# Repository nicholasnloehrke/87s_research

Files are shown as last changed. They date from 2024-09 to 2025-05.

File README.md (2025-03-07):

# Code and hardware design files

## Block diagram

### Overall system

> TODO

### Controller 

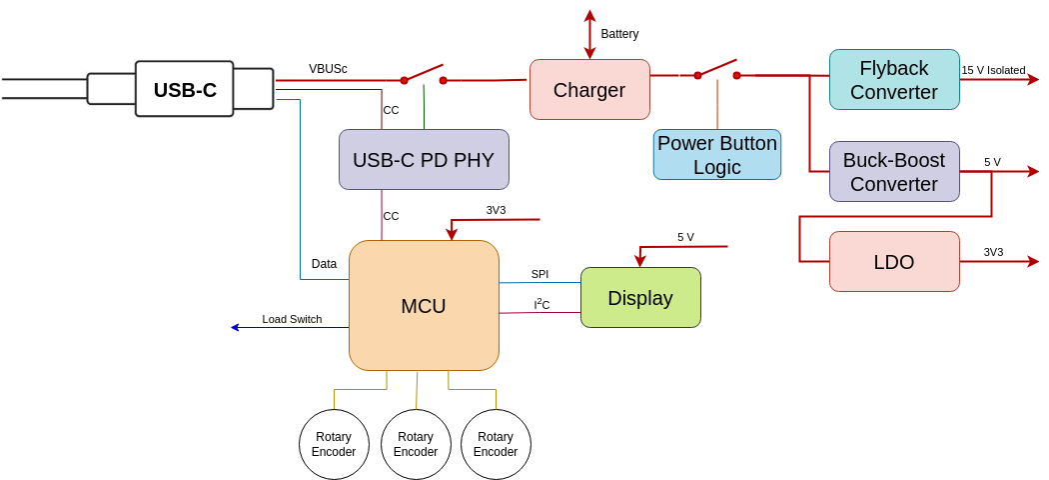
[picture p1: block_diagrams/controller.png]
controller_block_diagram


## Boards

### Bidirectional Load Switch

#### Known issues

- v0.1.0
    - Insufficient spacing on the AC connector 'AC\_in' net to 'earth' net
        - Workaround: Manually increase spacing
    - Lack of diode inline with 5 volt supply which would cause an issue if 5 volts and 3v3 (from ISP header) are supplied simultaneously 
        - Workaround: Don't supply both simultaneously
    - Lack of pulldown resistor on the !fault signal from the Attiny85 which could potentially have the gate driver inputs float, resulting in sporadic channel activation
        - Sporadic activation is likely only possible during power cycling as the gate drivers are internally pulled down.

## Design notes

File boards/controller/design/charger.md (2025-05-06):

# Charger IC's
    - BQ24707x
        - old
    - BQ24715
        - EVM avaliable
    - BQ24725A
        - EVM avaliable
    - BQ24735
        - EVM avaliable
    - BQ25792
        - EVM avaliable
        - Integrated FETs
        - Probably the easiest to design, assuming it meets the required specs

# Fuel Gauges
    - MAX17263

# BQ25792
    - Ship mode?
    - No USB D+/-?
    - V_AC?
    - Support 2-cell only?
        - If no, hardware jumpers or software configuration?
        - PROG pin sets *default* cell count, but can this be configured at runtime?
        - Seems like setting PROG to 1-cell and then configuring at runtime is possible.
          Need to consider safety concerns if MCU is setting charge voltages

## BQ25792 Power Sequencing
    - Minimum working voltage (rising)
        - VBAT
            - Min: 3.25, nominal: 3.40, max: 3.55 (ship mode)
            - Min: 2.50, nominal: 2.60, max: 2.71 (normal mode)
        - VBUS
            -

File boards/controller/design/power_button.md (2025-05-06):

# Power Button

The controller will implement a soft latching power circuit, as described
[here](https://circuitcellar.com/resources/quickbits/soft-latching-power-circuits/).
While it's possible to put the MCU and other peripherals into a sleep state,
removing power completely will result in the longest battery life in an off
state. Additionally, the LCD used was not designed with low power in mind, so
even in a sleep state there will be considerable power draw.

## Components
- Momentary switch
- Load switch (either an IC or discrete PMOS)
    - SIP32434ADN-T1E4

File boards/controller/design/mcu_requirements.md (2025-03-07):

# MCU Requirements

> This is a living document and will be updated continuously as requirements change

## Table

| Category | Requirement | Amount | Details |
|---|---|---|---|
| Memory | RAM | 700kB (min), ~1MB+ (preferred) | Needed for frame buffers (~614kB), LVGL (~48kB), and RTOS overhead |
| | Flash | 200kB (min), 1MB+ (preferred)  | LVGL (~100kB), FreeRTOS (~64kB). External QSPI flash likely needed with 200kB |
| Performance | General | N/A | Any MCU meeting RAM/Flash requirements should be sufficient |
| Peripherals | PWM | 1x (min), 8x (preferred) | For load switch channels |
| | SPI | 1x | Display |
| | I2C | 0x, 1x (preferred) | Display touch controller and STUSB4500 |
| | USB | 1x | For firmware updates and potential data logging |
| | QSPI | 0x, 1x (preferred) | For external flash |
| | GPIO | TBD | Needed for encoders, load switch, expansion |

## Discussion

### Memory

#### RAM

Fitting two frame buffers in memory would be ideal to allow for double buffering.  Tentatively, a 320 x 480 16BPP
display is to be used, requiring ~614kB for two buffers. LVGL claims 4kB + 150B/widget or '~48kB for a UI with a few
screens'. If we use a RTOS, extra RAM for thread stacks would be nice. With these considereations in mind, 700kB is
required and ~1MB or more of system RAM is preferred. 

#### Flash

I don't have a good idea of the flash requirements yet. LVGL wants ~100kB (depending on enabled features) and FreeRTOS
wants ~64kB (this is with TCP stack which we don't care about). More is certainly better, but we could probably get away
with some external QSPI flash if needed. I'm going to say ~200kB of onboard flash is a hard requirement, with 1MB total
being a nice to have. The tentative display has SD card support, but that uses the same SPI bus as the display driver,
so that's not ideal for reading/writing except at initialization.

### Performance

Performance is important, but just about any MCU that meets the RAM/flash requirements will be sufficient.

### USB-C Power Delivery

The STM32U5* chips have an integrated USB-C PD controller, but to reduce development time/complexity, I think using a
standalone STUSB4500 PD controller makes sense. It will take up some more board area and increase BOM count + cost, but
I think it still makes sense and reduces power sequencing complexity.

# Options
- STM32U575CGU3
    - Cheapest MCU on Digikey (thats in stock) that fits requirements
- STM32U575RITx
    - Similar to above, but with more IO

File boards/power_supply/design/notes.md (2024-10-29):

- BMS
    - https://liionbms.com/php/bms_chips_options.php
    - LTC6803
    - BQ769x0
    - ISL94202
    - ISL78600
    - L99BM114
    - LTC3300
    - LTC6804

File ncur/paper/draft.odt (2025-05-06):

Load Switch Circuit Module

The load switch circuit has seen significant improvements over the previous version. Version 2.0 retains the core design of back-to-back N-channel MOSFETs forming an AC switch but replaces the single-channel configuration and rotary switch for load selection [old schematic figure] with eight parallel switching channels [new schematic figure]. This upgrade allows for a much wider range of load resistances, as each channel can be independently controlled [resistance range figure]. The previous design faced reliability issues due to the rotary switch, a problem now eliminated with the solid-state implementation. Additionally, the new load switch integrates a microcontroller that reads an onboard Hall effect current sensor, providing over-current protection. The board maintains full compatibility with the previous version, supporting a single pulse-width modulation (PWM) input while also allowing up to eight PWM inputs for independent channel control. Each of the switching channels features galvanically isolated gate drivers with a working isolation voltage of 3.75 kVrms. The board logic side is powered by 5 VDC and the gate drivers are powered by an isolated 15-20 VDC supply. The onboard microcontroller provides either a simple GPIO interface, or UART.

Power Supply Module

The power supply module (PSM) has two primary functions: generating voltage rails and charging the battery. It utilizes two buck-boost converters to produce 5 VDC and 15 VDC power rails, with the 15 VDC rail isolated via a flyback converter. Texas Instruments TPS552872 buck-boost converters were selected for their wide input voltage range, enabling compatibility with various battery configurations. These converters also feature built-in protections, including output overvoltage protection, output short-circuit protection, and thermal shutdown. Designed to support 1–3 cell lithium-ion batteries, the PSM integrates a switch-mode battery charger from Monolithic Power Systems, offering configurable charge current and end-voltage settings. An onboard STM32U5 microcontroller negotiates power from any USB-C Power Delivery-compatible supply for charging. [schematic figure]

Battery Management System Module

Haven’t figured this part out yet, not sure if it should be included.

Microcontroller Unit

The microcontroller unit is built around an STM32U5, handling user input, display control, load switching, and USB communication. Menu navigation is achieved using three rotary encoders, allowing precise control of settings displayed on a 3.5-inch capacitive touch screen. The display operates over an SPI interface, while touch inputs are processed separately via an I2C bus to ensure smooth and responsive interaction.

To control the load switch, the microcontroller generates PWM signals with adjustable frequency and duty cycle. Additionally, USB functionality supports firmware updates, allowing end-users to upgrade the system without requiring specialized programming tools. This ensures long-term maintainability and easy deployment of software improvements or feature enhancements. [controller figure]

Comments/Questions

- How in-depth should I be going on the design process?
  - I could expand a ton on part selection, design tools, software, etc
- Keep power supply and microcontroller unit split up?
  - The initial design had separate boards, but now I’ve combined the functionally
- Talk about BMS?
  - This is going to be a store-bought item so idk if it needs it’s own section

Next Steps

- Finish up ‘module’ sections
  - Need schematics/other figures
- Add Version 1.0 sections
- Get into lab next week to do functional testing and collect data
- Order controller parts by next week or it won’t get done

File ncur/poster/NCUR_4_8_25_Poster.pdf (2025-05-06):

# University of Wisconsin-Platteville Electrical & Computer Engineering Department

# NATIONAL CONFERENCE ON UNDERGRADUATE RESEACHCUR 2025 Generator Stator Intermittent Ground Fault Test Instrument - Version 2.0

## Abstract:

The paper describes the design and fabrication of a novel intermittent ground fault (IGF) test instrument which aids system protection engineers to obtain solid or arcing fault data for evaluation of industrial generator stator ground protective relay settings.

# Nick Loehrke, Nader Safari-Shad, Owen Bauman, and Mason Kobliska

## Introduction:

Synchronous generators are critical to the stability and reliability of the power grid, making their protection against electrical faults essential for national security.
The most common generator fault is the stator single-phase ground fault which often begins as an intermittent ground fault (IGF). IGFs are characterized by high transient currents and overvoltages that can cause severe damage to insulation and generator components, potentially escalating into more severe faults and resulting in costly repairs and downtime.
Reports of stator IGF have sparked a renewed interest to develop reliable IGF detection schemes [1]-[3]. Specifically, [3] reports on development of a novel test instrument called 64S/87-TI version 1.0 by which stator IGF can be safely emulated on real-world generator stator neutral grounding circuits. Acquisition of such fault data can readily enable protective relay engineers to analyze the performance of new IGF detection schemes.
The goal of this paper is to propose upgrades to enhance the functionality of the 64S/87-TI version 1.0 reported in [3]. The primary upgrades include redesigning the electronic circuitry to incorporate a custom power supply module, battery management system, and improved load switch topology. The Arduino UNO microcontroller (MCU) used in [3] is also replaced with an STM32 MCU, offering increased processing power and flexibility. Additionally, the instrument enclosure is completely redesigned using a combination of extruded aluminum and CNC machined panels to ensure resilience to physical stresses.

## Conclusion:

## References:

[1] - IEEE Power System Relaying and Control Committee (PSRC) J12 Subcommittee Technical Report, “Improved Generator Ground Fault Schemes,” IEEE Power and Energy Society Technical Report -TR82, Sept. 1, 2020.
[2] - N. Safari-Shad, A. Sawadogo, R. Fechat and R. Franklin, ``Experimental Verification of an Intermittent Stator Ground Protection in Large MVA Generators," IEEE 26th International Conference on Electrical Machines, Torino, Italy, Sept. 1-4, 2024.
[3] - N. Safari-Shad and R. Franklin, ``Stator Intermittent Ground Fault Detection in High-Impedance Grounded Generators," IEEE 32nd International Symposium on Industrial Electronics, Aalto University, Helsinki-Espoo, Finland, June 19-21, 2023.

## Bidirectional Load Switch Module:

Fig. 3 shows the printed circuit board of the bidirectional load switch consisting of multiple fault resistance path to ground, MOSFET switches, and their gate drivers.

## Power Supply Module:

Fig. 2: Block diagram of the 64S/87TI

## Enclosure Design:

Fig. 1: Typical synchronous generator stator windings and connected protection equipment with the 64S/87S-TI

## Experimental Intermittent Ground Fault Realization:

64S/87S-TI is capable of staging solid or arcing single-phase ground fault on a real-world generator neutral or terminal phases. Fig. 1 shows the wiring diagram of a high impedance synchronous generator with the 64S/87-TI shown connected on the neutral point. Note that the generator stator ground protection is using a 64S subharmonic voltage injection along with a bandpass filter.

## 64S/87STI Version 2.0 Overall Architure:

Fig. 2 shows the overall block diagram of the 64S/87TI consisting of a battery, a battery management system (BMS), a custom designed power supply unit (PSU), a microcontroller (MCU), a bidirectional load switch circuit and a display.

Fig. 3: Block diagram of the 64S/87TI bidirectional switch circuit

Fig. 4: Block diagram of the 64S/87TI power supply module

## Microcontroller Unit:

Fig. 5: Block diagram of the of the 64S/87TI MCU

## Battery Management System:

Fig. 5: Block diagram of the 64S/87TI battery management system

Fig. 6: 64S/87S-TI Version 2.0 enclosure design

AC IN

CT IN | EARTH

CT OUT

CT

BNC

SCOPE

nINT

64S/87S -TI

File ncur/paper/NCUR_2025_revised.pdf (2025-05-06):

# Generator Stator Intermittent Ground Fault Test Instrument - Version 2.0

Nick Loehrke, Nader Safari-Shad, Owen Bauman, Electrical and Computer Engineering Department University of Wisconsin-Platteville Platteville, WI 53818, USA loehrken@uwplatt.edu
safarisn@uwplatt.edu
baumano@uwplatt.edu

Mason Kobliska
Huff Family Innovation Center
College of Engineering, Mathematics and Science University of Wisconsin-Platteville Platteville, WI 53818, USA kobliskam@uwplatt.edu

Abstract—The paper describes an improved design and fabrication of a novel intermittent ground fault (IGF) test instrument used in industrial generator stator ground protection. The improved instrument allows staging and acquisition of IGF data with higher precision and reliability. The instrument also enables more effective testing and validation of IGF detection algorithms contributing to the prevention of catastrophic generator stator ground faults and enhancing grid reliability.

Index Terms—Generator stator ground fault protection, and subharmonic voltage injection-based (64S) scheme.

I. INTRODUCTION

Synchronous generators are critical to the stability and reliability of the power grid, making their protection against electrical faults essential for national security.
The most common generator fault is the stator single-phase ground fault which often begins as an IGF. IGFs are characterized by high transient currents and overvoltages that can cause severe damage to insulation and generator components, potentially escalating into more severe faults and resulting in costly repairs and downtime [1] - [5].
Reports of stator IGF have sparked a renewed interest to develop reliable IGF detection schemes [6] - [8]. Specifically,
[8] reports on development of a novel test instrument called 64S/87S-TI Version 1.0 by which stator IGF can be safely emulated on real-world generator stator windings resulting in valuable fault data. Acquisition of such fault data enables protective relay engineers to analyze the performance of IGF detection schemes and assess their reliability.
The goal of this paper is to report on the upgrades enhancing the functionality of the 64S/87S-TI Version 1.0. The primary upgrades include redesigning the electronic circuitry to incorporate a custom power supply, battery management system, and improved load switch topology. The Arduino UNO microcontroller (MCU) in the 64S/87S-TI Version 1.0 is replaced with an STM32 MCU, offering increased processing power and flexibility. Additionally, the instrument enclosure is completely redesigned using a combination of extruded aluminum and CNC machined panels to ensure resilience to physical stresses.

II. IGF TEST INSTRUMENT - VERSION 1.0

The IGF test instrument named the 64S/87S-TI is an instrument designed and manufactured for stator insulation condition diagnosis in high-impedance grounded (HIG) generators [8]. Fig. 1 shows the typical schematic of the neutral grounding circuit equipped with the subharmonic voltage injection protection scheme 64S [9]. The 64S scheme is implemented using a subharmonic injection source, a bandpass filter,
a 64S protective relay [10], a current transformer (CT) | [11],
and | a neutral grounding transformer and resistor.

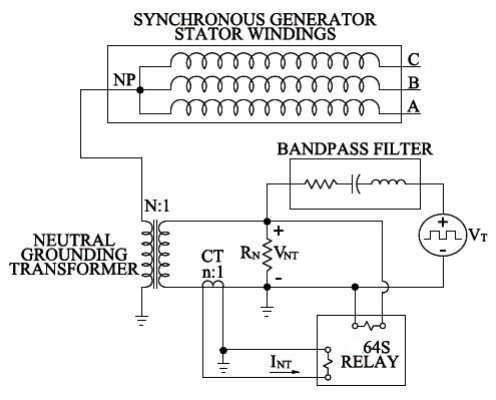
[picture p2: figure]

Fig. 1. Implementation of the 64S scheme in HIG generators

The instrument’s main function is to stage stator ground faults and measure the primary neutral grounding current on the grounding transformer low voltage side [8]. Two types of ground faults can be staged using the instrument: solid ground fault (SGF) and intermittent ground fault (IGF). Fig. 2 displays the front panel of the instrument.

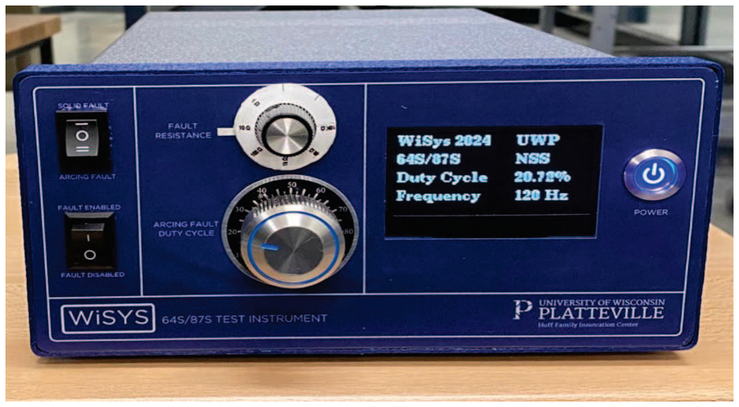
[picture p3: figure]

Fig. 2. IGF Test instrument - Version 1.0

A. SGF/IGF Test Setup

Fig. 3 shows the wiring diagram from the 64S/87S-TI to the generator neutral point. The setup is used for staging a solid or intermittent ground fault on the neutral side of the generator. When it is desired to stage a solid or intermittent ground fault on the terminal side of the generator, the AC IN connection is moved to one of the phases A, B, or C. The AC IN, EARTH, CT IN, and CT OUT connections are bundled in one plug-in port, respectively. The CT IN/OUT are, respectively, the input and output of a high-fidelity CT inside the 64S/87S-TI. The CT is capable of measuring high frequency neutral grounding current activity during intermittent ground fault [12].

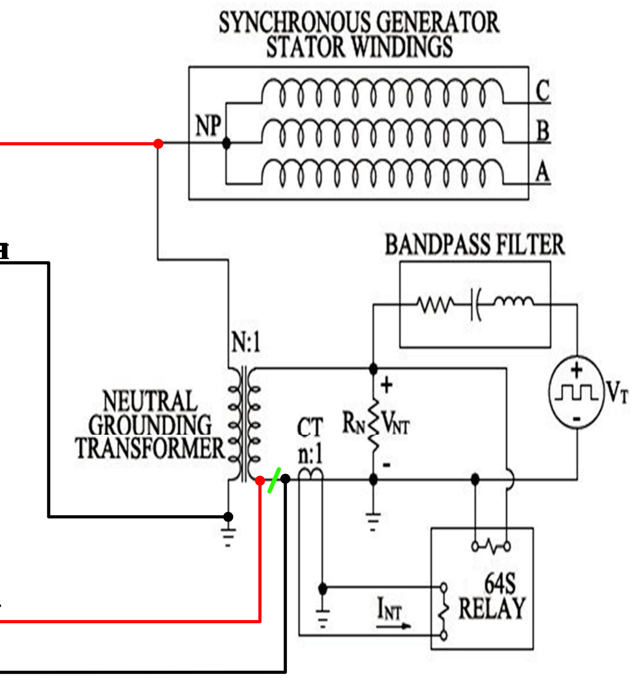
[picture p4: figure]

Fig. 3. 64S/87S-TI wiring connection diagram for fault staging

The principal component of the 64S/87S-TI is a single-channel AC bidirectional switch with a pair of MOSFETs, a gate driver IC and an Arduino UNO MCU. Moreover, a rotary switch is used for fault resistance selection. The complete assembly is referred to as the load switch circuit and is shown

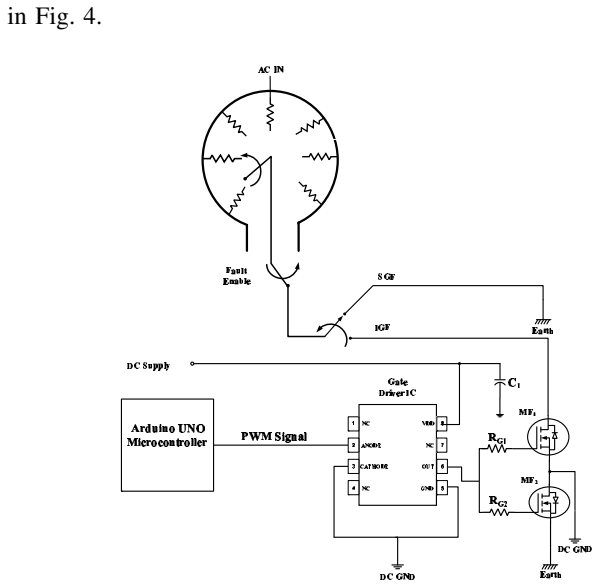
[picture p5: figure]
in Fig. 4.

Fig. 4. Load switch circuit in 64S/87S-TI - Version 1.0

III. IGF TEST INSTRUMENT - VERSION 2.0

The Version 1.0 of the instrument has been successfully implemented on a lab model of HIG generators to verify the reliability of a novel IGF detection scheme called the 87S [8]. However, in the process of this verification, a number of upgrades have been deemed necessary to improve the instrument’s functionality and performance. Specifically, the simple rechargable lithium-ion battery in Version 1.0 has been upgraded to an electronic circuitry for regulated power supply at 5VDC and 15VDC. In addition, a battery management system has been added to provide information on the state of battery charge. Moreover, the load switch circuit topology has been completely redesigned for optimal performance and its Arduino UNO MCU has been replaced with an STM32 MCU, offering increased processing power and flexibility. Finally, the instrument’s enclosure is completely redesigned using a combination of extruded aluminum and CNC machined panels to ensure resilience to physical stresses. The subsequent sections provide further details on all the upgrades.

A. Load Switch Circuit Module

The load switch circuit has seen significant improvements over the previous version. Version 2.0 retains the core design of the AC bidirectional switch shown in Fig. 4, but replaces the single-channel configuration and rotary switch for load selection with eight parallel switching channels as shown in Fig. 5.

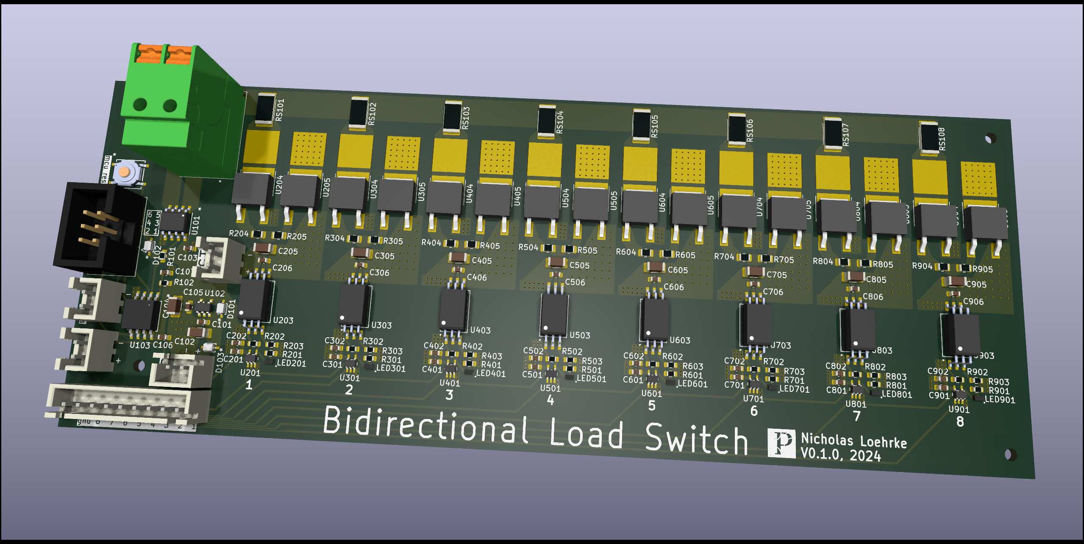
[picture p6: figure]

Fig. 5. Upgraded load switch circuit

This upgrade allows for a much wider range of fault resistances, as each channel can be independently controlled [resistance range figure]. The previous design faced reliability issues due to the rotary switch, a problem now eliminated with the solid-state implementation. Additionally, the new load switch integrates a microcontroller that reads an onboard Hall effect current sensor, providing overcurrent protection. The board maintains full compatibility with the previous version, supporting a single pulse-width modulation (PWM) input while also allowing up to eight PWM inputs for independent channel control. Each of the switching channels features galvanically isolated gate drivers with a working isolation voltage of 3.75 kVrms. The board logic side is powered by 5 VDC and the gate drivers are powered by an isolated 15-20 VDC supply. The onboard microcontroller provides either a simple GPIO interface, or UART.

B. Power Supply Module
The power supply module (PSM) has two primary functions: generating voltage rails and charging the battery. It utilizes two buck-boost converters to produce 5 VDC and 15 VDC power rails, with the 15 VDC rail isolated via a flyback converter. Texas Instruments TPS552872 buck-boost converters were selected for their wide input voltage range, enabling compatibility with various battery configurations. These converters also feature built-in protections, including output overvoltage protection, output short-circuit protection, and thermal shutdown. Designed to support 1−3 cell lithium-ion batteries, the PSM integrates a switch-mode battery charger from Mono-

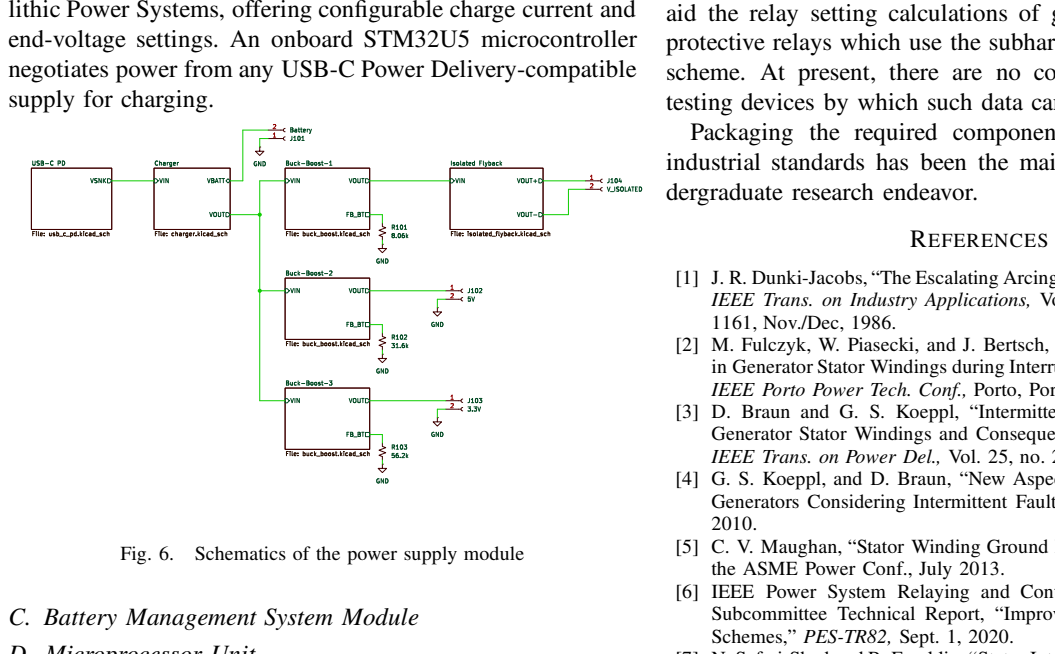
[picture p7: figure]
supply for charging.; C. Battery Management System Module; dergraduate research endeavor.; REFERENCES; 1161, Nov./Dec, 1986.; the ASME Power Conf., July 2013.; Schemes,” PES-TR82, Sept. 1, 2020.

lithic Power Systems, offering configurable charge current and end-voltage settings. An onboard STM32U5 microcontroller negotiates power from any USB-C Power Delivery-compatible

Fig. 6. Schematics of the power supply module

D. Microprocessor Unit
The microcontroller unit is built around an STM32U5, handling user input, display control, load switching, and USB communication. Menu navigation is achieved using three rotary encoders, allowing precise control of settings displayed on a 3.5-inch capacitive touch screen. The display operates over an SPI interface, while touch inputs are processed separately via an I2C bus to ensure smooth and responsive interaction. To control the load switch, the microcontroller generates PWM signals with adjustable frequency and duty cycle. Additionally, USB functionality supports firmware updates, allowing end-users to upgrade the system without requiring specialized programming tools. This ensures long-term maintainability and easy deployment of software improvements or feature enhancements. Fig. 7 shows the STM32U5 and the ancillary subsystems of the instrument.

IV. ENCLOSURE REDESIGN AND FABRICATION

V. FUNCTIONAL TESTING

VI. CONCLUSION
The paper describes the detailed steps to manufacture an enhanced version of an intermittent ground fault testing in-

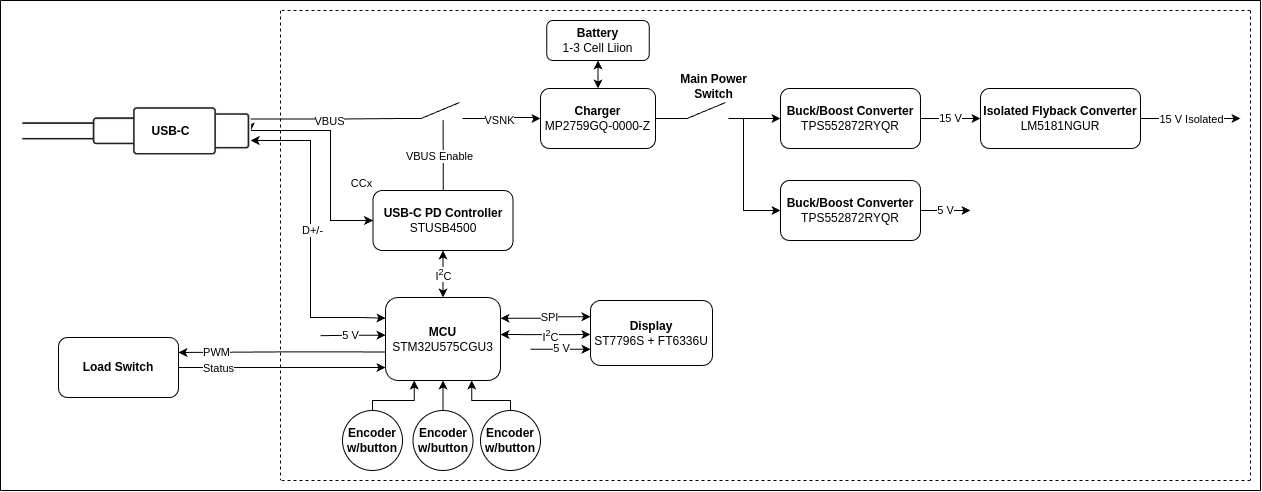
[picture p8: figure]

Fig. 7. Block diagram of the controller and the ancillary subsystems

strument by which generator stator intermittent and/or solid ground fault data can be simulated and stored. The stored data aid the relay setting calculations of generator stator ground protective relays which use the subharmonic voltage injection scheme. At present, there are no commercial ground fault testing devices by which such data can be collected. Packaging the required components in accordance with industrial standards has been the main objective of this un-

[1] J. R. Dunki-Jacobs, “The Escalating Arcing Ground-Fault Phenomenon,” IEEE Trans. on Industry Applications, Vol. IA-2225, no. 6, pp 1156-
[2] M. Fulczyk, W. Piasecki, and J. Bertsch, “Fast Transient Overvoltages in Generator Stator Windings during Interrupted Arcing Ground-Faults,” IEEE Porto Power Tech. Conf., Porto, Portugal, Sept. 2001.
[3] D. Braun and G. S. Koeppl, “Intermittent Line-to-Ground Faults in Generator Stator Windings and Consequences on Neutral Grounding,” IEEE Trans. on Power Del., Vol. 25, no. 2, pp 876-881, Apr. 2010.
[4] G. S. Koeppl, and D. Braun, “New Aspects for Neutral Grounding of Generators Considering Intermittent Faults,” CIDEL Argentinak, Sept.
[5] C. V. Maughan, “Stator Winding Ground Protection Failures,” Proc. of
[6] IEEE Power System Relaying and Control Committee (PSRC) J12 Subcommittee Technical Report, “Improved Generator Ground Fault
[7] N. Safari-Shad and R. Franklin, “Stator Intermittent Ground Fault Detection in High-Impedance Grounded Generators,” IEEE 32nd International Symposium on Industrial Electronics, Aalto University, Helsinki-Espoo, Finland, June 19-21, 2023.
[8] N. Safari-Shad and R. Franklin, “Experimental Verification of an Intermittent Ground Fault Detection in Large MVA Generators,” IEEE 26th International Conference on Electrical Machines, Torino, Italy, Sept. 1-4, 2024.
[9] S. Turner, “Applying 100% Stator Ground Fault Protection by Low Frequency Injection for Generators,” in Proc. IEEE Power Energy Soc. Gen. Meeting, pp. 1-6, Jul. 2009.
[10] “Beckwith Electric, M3425A Generator Protection Relay Instructional Book,” Beckwith Electric Inc. Publication.
[11] Flex Core Current Transformer, https://www.flex-core.com.
[12] MagneLab Current Transformer, https://gmw.com/product/ct/.

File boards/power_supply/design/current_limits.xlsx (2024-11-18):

Cell Charge Voltage | Charge Current |  | Voltage | Current | Power | PDO\Cell Count | 1 | 2 | 3
4.2 | 2 | PDO1 | 5 | 1 | 5 | PDO1 | no | no | no
 |  | PDO2 | 9 | 2 | 18 | PDO2 | yes | no | no
VIN to VBATT delta: | 2.4 | PDO3 | 15 | 2 | 30 | PDO3 | yes | yes | yes

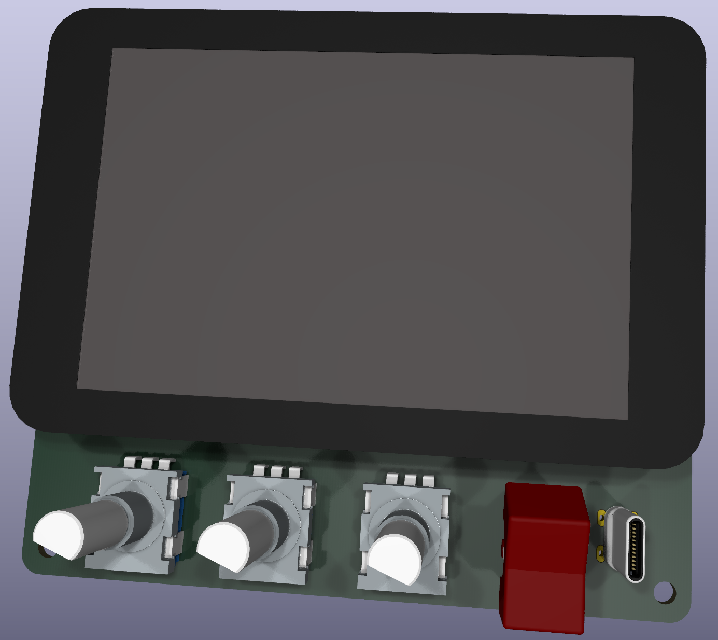
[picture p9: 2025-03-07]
ncur/media/controller-mockup-render.png

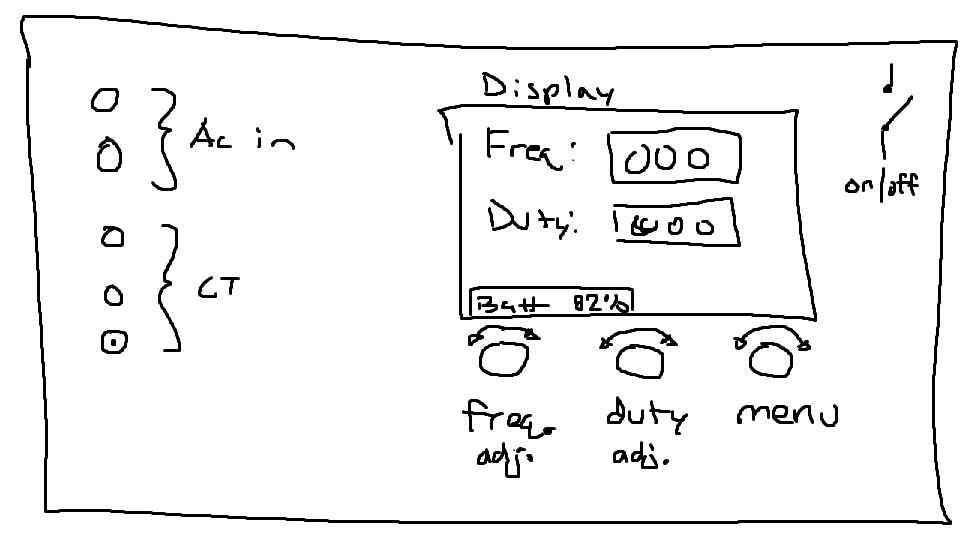
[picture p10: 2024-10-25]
docs/really_professional_front_panel_mockup.png

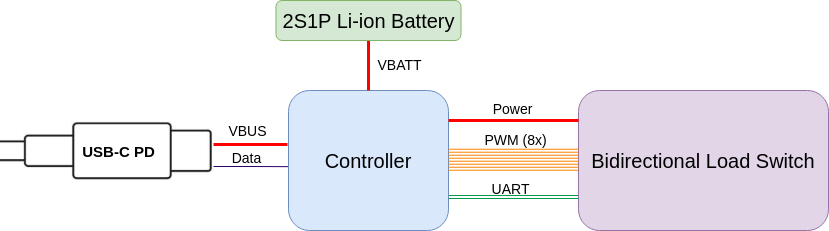
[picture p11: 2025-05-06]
block_diagrams/complete_system.png

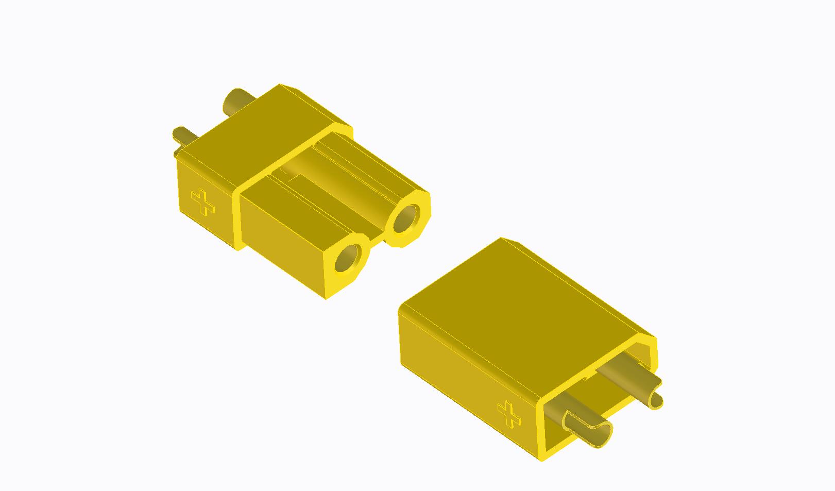
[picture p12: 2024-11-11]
boards/controller/pcb/symbols/XT30/XT30.jpg

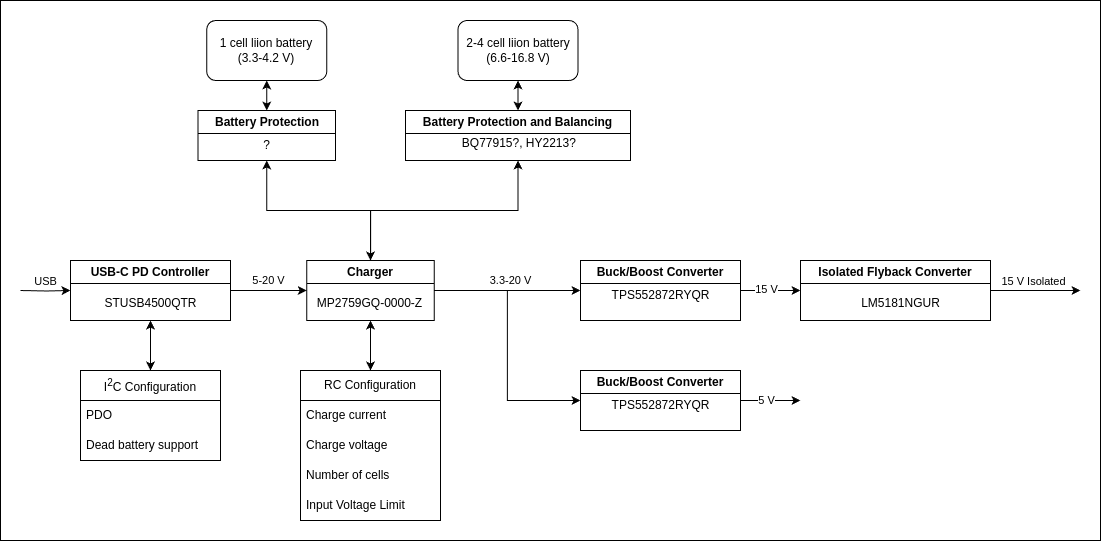
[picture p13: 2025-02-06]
block_diagrams/power_supply.png

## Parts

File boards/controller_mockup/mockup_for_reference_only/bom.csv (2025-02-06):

part | mfg_number | link
display | 3.5inch Capacitive Touch LCD 29318 | https://www.waveshare.com/3.5inch-Capacitive-Touch-LCD.htm
microcontroller | STM32U575CGU6Q | https://www.digikey.com/en/products/detail/stmicroelectronics/STM32U575CGU6Q/18086269
encoder | PEC12R-4120F-S0012 | https://www.digikey.com/en/products/detail/bourns-inc/PEC12R-4120F-S0012/4499657

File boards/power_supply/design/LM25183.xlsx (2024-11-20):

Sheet: LM(2)518x PSR flyback converter
LM5180/1 and LM25180/3/4 PSR Flyback Design Tool
About | xx (http://www.ti.com/widevin) |  |  | = Input Box |  |  |  |  |  | Terms Of Use
Step 1: Operating Specifications |  |  |  |  |  | Step 2: Flyback Transformer
 |  | Input Voltage – Min, VIN(min) | 9 | V |  |  | Minimum Magnetizing Inductance | 50.8 | µH
 |  | Input Voltage – Nom, VIN(nom) | 20 | V |  |  | Magnetizing Inductance, LMAG | 150 | µH
 |  | Input Voltage – Max, VIN(max) | 21 | V |  |  | Primary Winding DCR | 800 | mΩ
 |  | Single Output or Dual Outputs |  |  |  |  | Secondary Winding DCR | 796 | mΩ
 |  | Output Voltage, VOUT | 20 | V |  |  |  | 50
 |  | Rated Output Current, IOUT | 0.1 | A |  |  | Pri-Sec Leakage Inductance | 3000 | nH
 |  |  | -16 |  |  |  | Transformer Turns Ratio, Pri : Sec
 |  |  | -0.1 |  |  |  | SW Voltage at VIN(max) - Spike Not Included | 41 | V
 |  |  |  |  |  |  | Max Output Current at VIN(min) | 0.11 | A
Step 3: Input & Output Capacitors |  |  |  |  |  |  | Duty Cycle at VIN(min) | 69.4 | %
 |  | Minimum Input Capacitance | 2.2 | µF |  |  | Primary Winding DCR Loss at Vin(nom) | 36.481901 | mW
 |  | Input Capacitance, CIN | 10 | µF |  |  |  | 22.37904887 | mW
 |  | Input Capacitor ESR | 3 | mΩ |  |  | Peak Primary Current at Vin(nom) | 0.44 | A
 |  | Resulting Input Voltage Ripple | 36.50007233 | mVpk-pk |  |  | Peak Secondary Current at Vin(nom) | 0.44 | A
 |  | Minimum Output Capacitance | 7.557870065 | µF |  |  |  | 4.7 | µF
 |  | Output Capacitance, COUT | 20 | µF |  |  | Output Capacitance, COUT2 | 22 | µF
 |  | Output Capacitor ESR | 3 | mΩ |  |  | Output Capacitor ESR | 2 | mΩ
 |  | Resulting Output Voltage Ripple | 17.53692 | mVpk-pk |  |  |  | 12.83484433 | mVpk-pk
Step 4: Feedback, Soft-start, TC, UVLO
 |  | Recommended Feedback Resistor | 203.2 | kΩ
 |  | Selected Feedback Resistor, RFB | 203.2 | kΩ
 |  | Soft-Start Configuration
 |  | *Leave SS Pin Open or Supply by Ext. Bias | 20 | ms
 |  | Soft-Start Capacitance, CSS | 100 | nF
 |  | VOUT Thermal Compensation
 |  | *Leave TC Pin Open | -1.5 | mV/°C
 |  | Thermal Compensation Resistor, RTC | 402 | kΩ
 |  | Input UVLO Configuration
 |  | *Connect EN pin to VIN or Logic HIGH | 8 | V
 |  |  | 7.5 | V
 |  | Upper UVLO Resistor, RUV1 | 46.4 | kΩ
 |  | Lower UVLO Resistor, RUV2 | 10.7 | kΩ
Step 5: Power Losses & Thermals
 |  | Flyback Diode Voltage Drop, VD(no-load) | 0.32 | V
 |  | Flyback Diode Voltage Drop, VD(full-load) | 0.4 | V
 |  | Estimated IC Thermal Impedance, JJA | 41 | °C/W
 |  | Ambient Temperature, TA | 55 | °C
 |  | Power Dissipation at Full Load, PD | 46.71808189 | mW
 |  | Junction Temperature at Full Load, TJ | 56.91544136 | °C
Step 6: Optional RC Snubber across Rectifier Diode |  |  |  |  | (Always reserve the snubber positions on PCB, and validate by experiments.)
 |  | Recommended Csnb | 22 | pF
 |  | Snubber Capacitor Voltage Rating > | 61.5 | V
 |  | Recommended Rsnb | 100 | Ω
 |  | Snubber Resistor Power Dissipation Rating > | 0.116 | W
Step 7: Optional Output Zener Clamp or Dummy Load |  |  |  |  | (Always reserve the Zener clamp and dummy load position on PCB)
 |  | Min Load Current, IOUTmin | 0.005 | A |  |  |  | -0.005
 |  | Max Output Voltage Limit, VOUTmax | 22.00 | V |  |  |  | -17
 |  | Zener Clamp Dz or Dymmy Load Rdmy | None
 |  | Selection | None
 |  | Selected Device Min Power Rating> | N/A | W

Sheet: BOM & Schematic
SINGLE Output PSR Flyback Converter, VIN = 20 V, VOUT = 20 V, IOUT = 0.1 A
LM5181 High Efficiency PSR Flyback Converter BOM
Count | Ref Des | Value | Description | Size | Part Number | MFR | Footprint (mm) | Area (mm2)
1 | CIN | 10µF | Capacitor, Ceramic, 10µF, 50V, X7R, 10% |  | Std | Std | 3.2 x 2.5 | 8.0 |  |  |  | 5
1 | COUT | 20µF | Capacitor, Ceramic, 20µF, 25V, X7R, 10% |  | Std | Std | 3.2 x 2.5 | 8.0 |  |  |  | 5
- | COUT2 | - | - |  | - | - | - | - |  |  |  | 5
- | - | - | - | 0603 | - | - | - | - |  |  |  | 1
1 | DFLY | Diode | Rectifying Diode, Schottky | #NAME? | Std | Std | 5.0 x 2.5 | 12.5 |  |  |  | 4
- | DFLY2 | - | - | 0603 | - | - | - | - |  |  |  | 3
1 | DF | Diode | Clamp Circuit Diode, Fast Recovery |  | Std | Std | 3.6 x 1.8 | 6.5 |  |  |  | 3
1 | DCLAMP | 26V | Clamp Circuit Diode, Zener, 26V | 0603 | Std | Std | 3.6 x 1.8 | 6.5 |  |  |  | 3
1 | DOUT | 22V | Output Clamp Diode, Zener, 22.5V |  | Std | Std | 1.6 x 0.8 | 1.3 |  |  |  | 1
1 | RSET | 12.1k | Resistor, Chip,12.1kΩ, 1/16W, 1% | 0603 | Std | Std | 1.0 x 0.5 | 0.5 |  |  |  | 1
1 | RFB | 203.2k | Resistor, Chip,203.2kΩ, 1/16W, 1% | 0603 | Std | Std | 1.0 x 0.5 | 0.5 |  |  |  | 1
- | RUV1 | - | - | 0603 | - | - | - | - |  |  |  | 1
- | RUV2 | - | - | 0603 | - | - | - | - |  |  |  | 1
- | RTC | - | - | 0603 | - | - | - | - |  |  |  | 1
1 | T1 | 150µH | Transformer, 150µH, 1 : 1, 800mΩ Pri DCR, 1A Isat | - | Various | Various | 10 x 10 | 100 |  |  |  | 5
1 | U1 | LM5181 | IC, LM5181, PSR Flyback Converter, 4.5V–65V Input | WSON-8 | LM5181NGUR | TI | 4.0 x 4.0 | 16.0
 |  |  |  |  | Total Solution Size (buffered by 25%) |  |  | 199.8 | mm2 = | 0.3096 | in2
NOTES:
1. Choose a transformer with saturation current rating higher than the max peak current limit setting (1.73A) for all operating temperatures
2. Appropriately derate the effective input and output capacitances for applied voltage and temperature, particularly with ceramics
3. Use a primary-side RC snubber from SW to VIN to dampen leakage inductance spike
4. Use a flyback diode RC snubber to dampen ringing if needed
5. Use an output zener to clamp the output at no load

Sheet: EVM Examples Layouts
LM5180/1 and LM25180/3/4 PSR Flyback Converter Design Tool
 | LM5180EVM-S05 PCB Design, 2" x 1.4" (50mm x 35mm) | LM5180EVM-DUAL PCB design, 2.1" x 1.5" (55mm x 38mm) | LM25184EVM-S12 PCB design, 2.2" x 1.4" (56mm x 36mm)

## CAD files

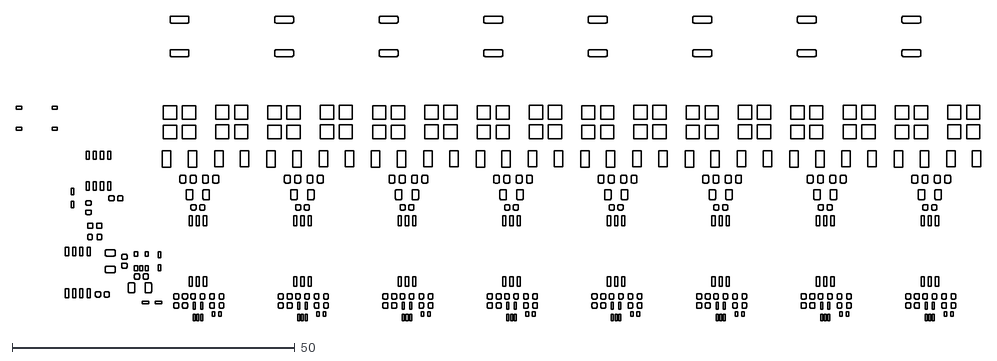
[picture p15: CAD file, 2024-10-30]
boards/bidirectional_load_switch/assembly/paste.dxf
170.7 x 53.9

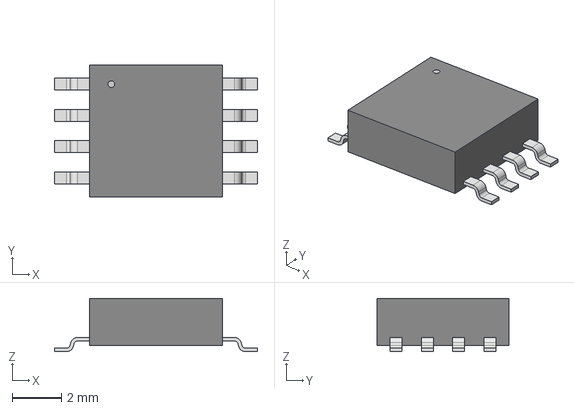
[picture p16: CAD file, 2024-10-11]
boards/bidirectional_load_switch/pcb/symbols/ATTINY85_20SU/8S2_ATM.step
8.26 x 5.36 x 2.16 mm

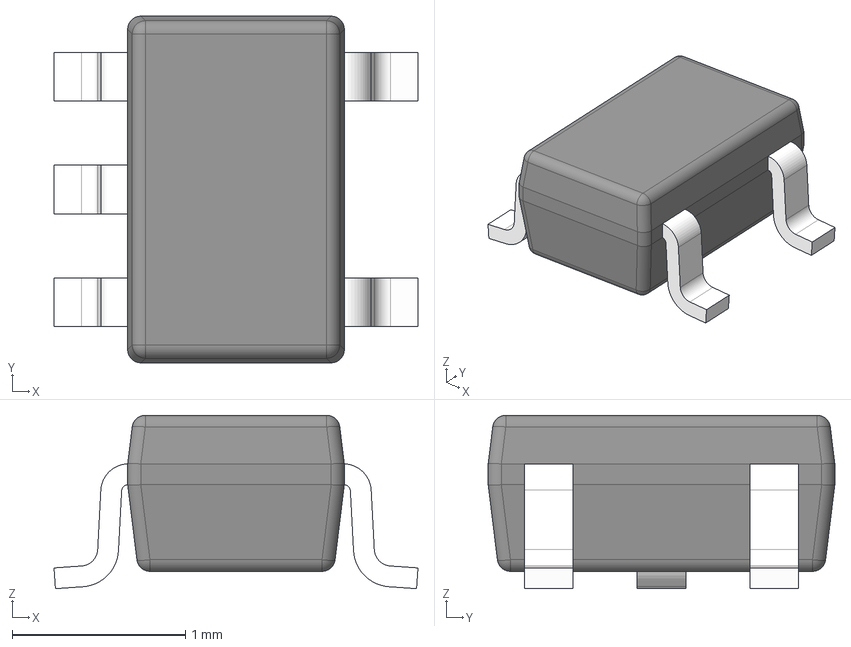
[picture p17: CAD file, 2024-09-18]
boards/bidirectional_load_switch/pcb/symbols/SN74LVC1G08DCKR/DCK0005A.stp
2.10 x 2.00 x 1.00 mm
BODY-SOT
LEAD-SOT x 5
PIN1-ID

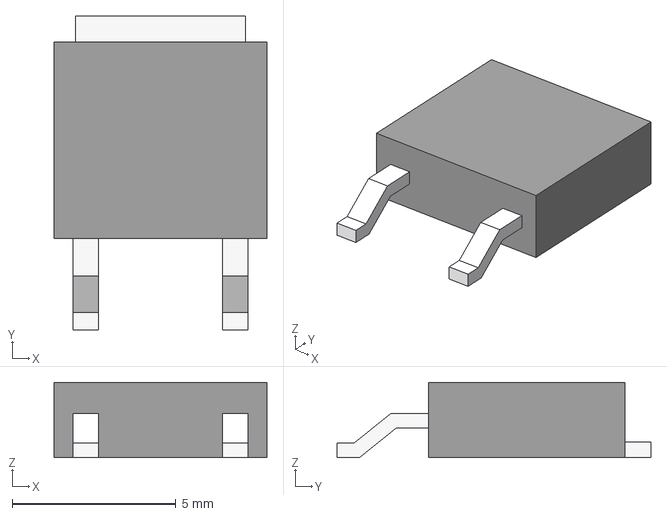
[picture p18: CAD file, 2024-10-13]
boards/bidirectional_load_switch/pcb/symbols/STD16N60M6/new_mosfet.step
6.50 x 9.60 x 2.30 mm

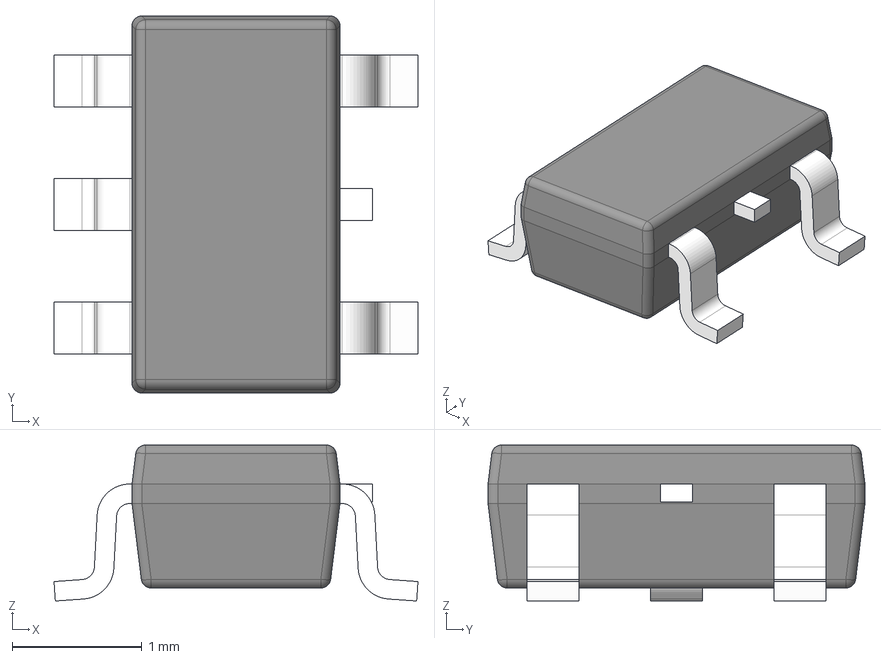
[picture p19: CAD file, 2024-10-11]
boards/bidirectional_load_switch/pcb/symbols/TLV75733PDBVR/DBV0005A.stp
2.80 x 2.90 x 1.20 mm
BODY-SOT
LEAD-SOT x 5
LEAD-DUMMY

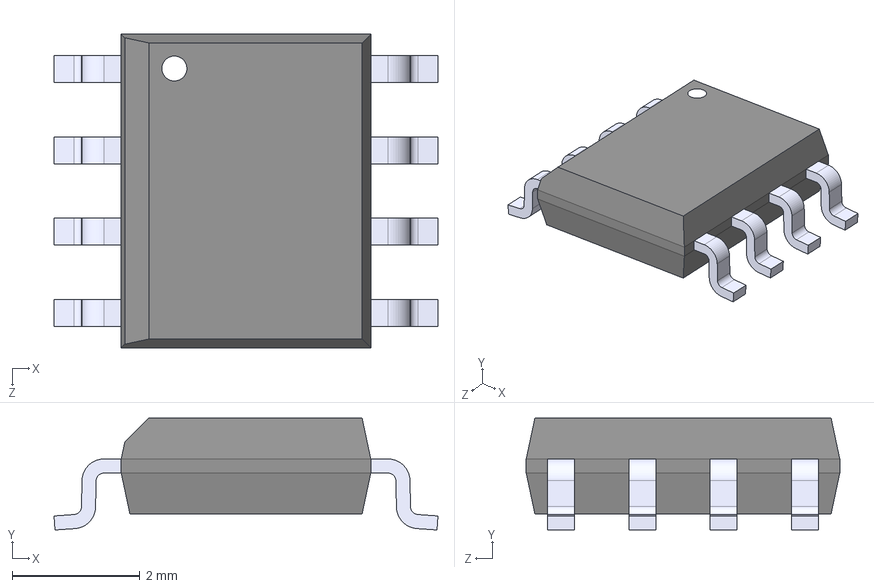
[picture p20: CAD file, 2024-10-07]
boards/bidirectional_load_switch/pcb/symbols/TMCS1101A3BQDR/TMCS1101A3BQDR.step
6.00 x 1.75 x 4.90 mm

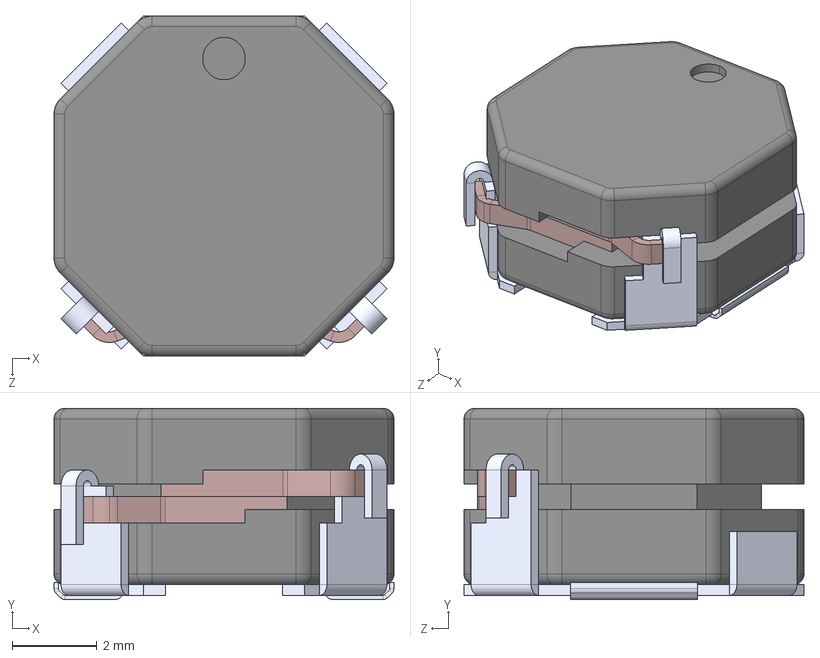
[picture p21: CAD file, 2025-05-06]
boards/controller/pcb/symbols/1217AS-H-3R3N-P3/1217AS-H-3R3N-P3.step
8.00 x 4.50 x 8.00 mm

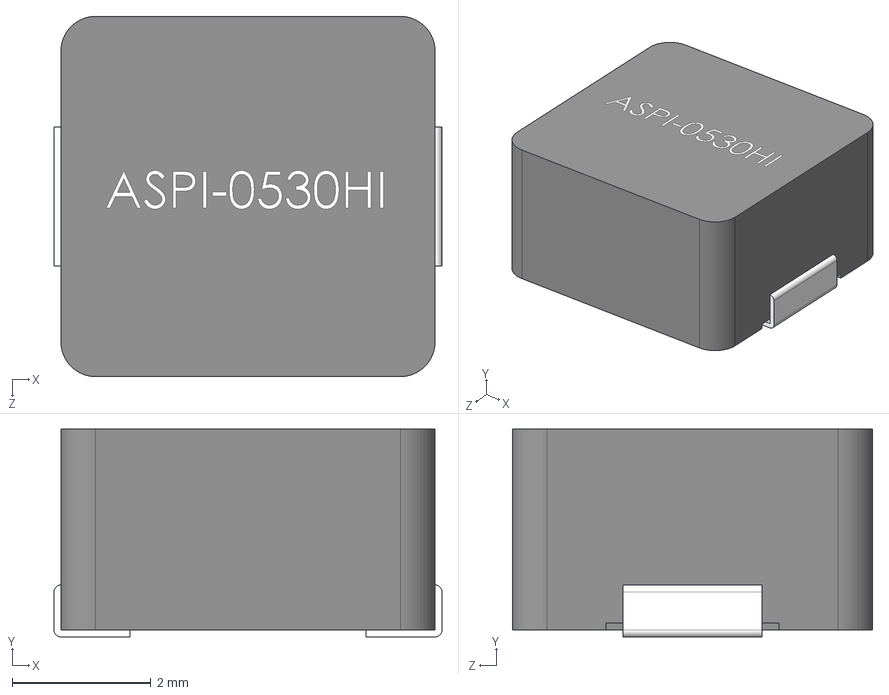
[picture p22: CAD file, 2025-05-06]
boards/controller/pcb/symbols/ASPI-0530HI-1R0M-T2/ASPI-0530HI-1R0M-T2.step
5.60 x 3.00 x 5.20 mm

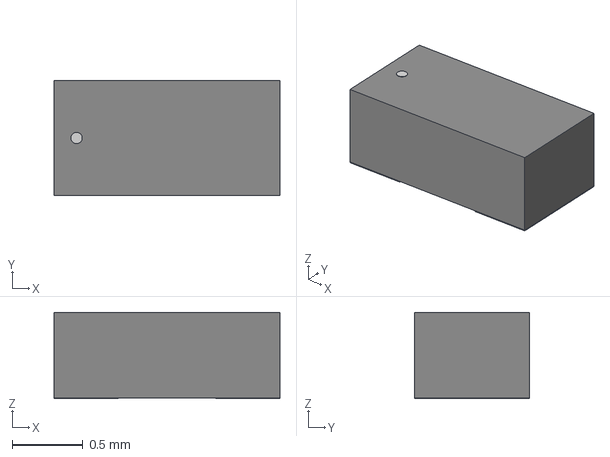
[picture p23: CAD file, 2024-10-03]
boards/controller/pcb/symbols/B1911PG--20D000514U1930/B1911PG--20D000514U1930.step
1.60 x 0.812 x 0.612 mm

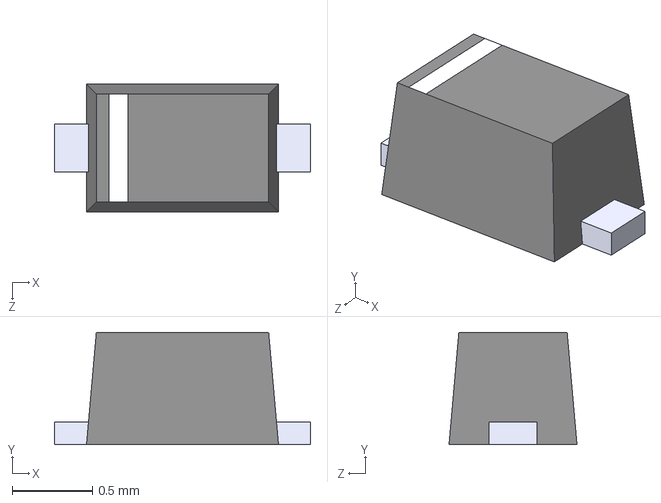
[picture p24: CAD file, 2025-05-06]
boards/controller/pcb/symbols/BZT52C18K_RKG/BZT52C18K_RKG.step
1.60 x 0.7 x 0.8 mm

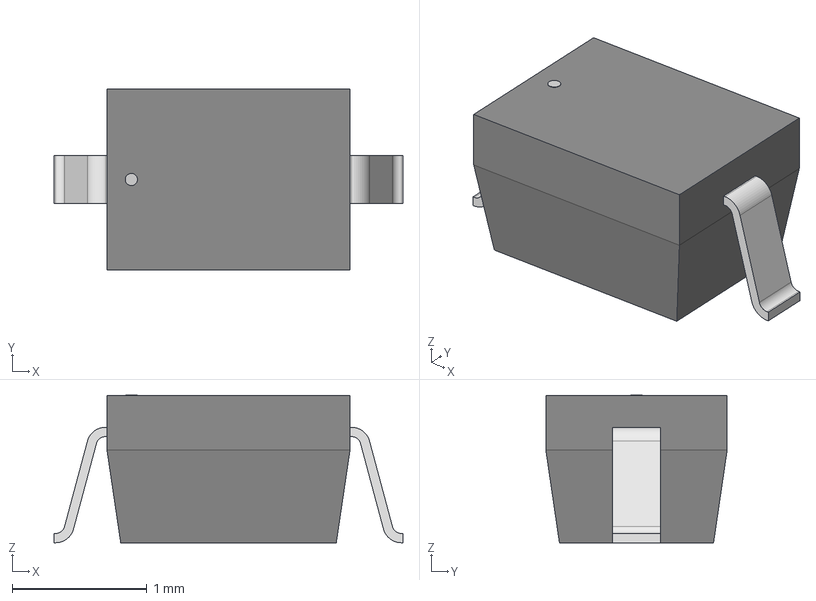
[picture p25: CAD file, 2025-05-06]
boards/controller/pcb/symbols/CMDD4448/CMDD4448.step
2.59 x 1.35 x 1.09 mm

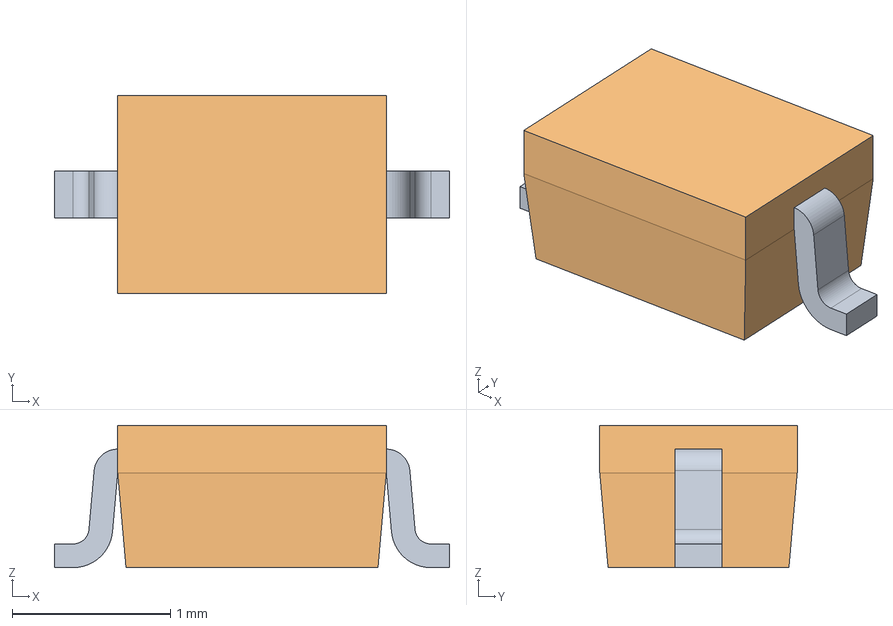
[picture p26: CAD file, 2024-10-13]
boards/controller/pcb/symbols/CUS10S30_H3F/CUS10S30_H3F.stp
2.50 x 1.25 x 0.9 mm

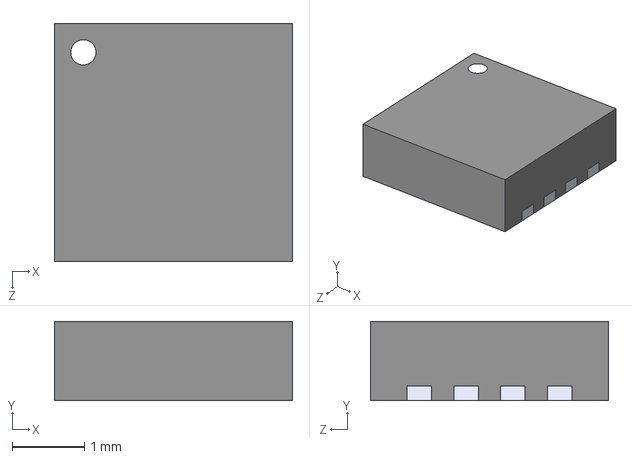
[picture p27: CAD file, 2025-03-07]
boards/controller/pcb/symbols/ISZ065N03L5SATMA1/ISZ065N03L5SATMA1.step
3.30 x 1.10 x 3.30 mm

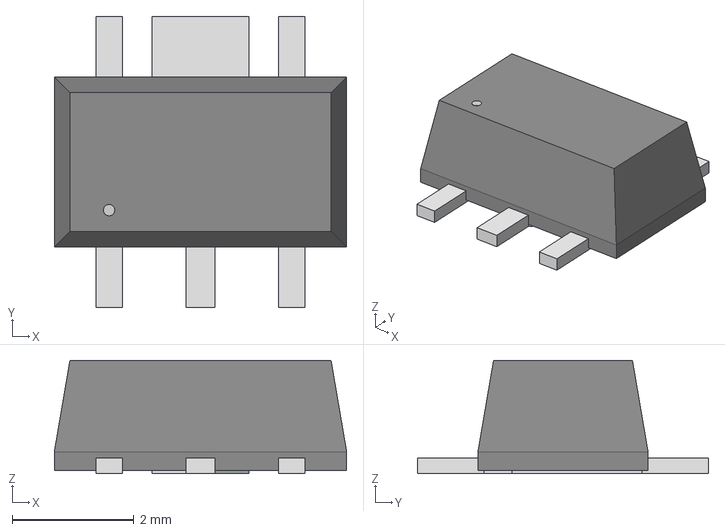
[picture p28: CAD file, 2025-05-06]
boards/controller/pcb/symbols/NJM2884U1-33-TE1/NJM2884U1-33-TE1.step
4.80 x 4.78 x 1.86 mm

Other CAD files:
boards/controller/pcb/symbols/PJSD03TS-AU_R1_000A1/PJSD03TS-AU_R1_000A1.step
boards/controller/pcb/symbols/RH100-16.000-18-2030-EXT-TR/RH100-16.000-18-2030-EXT-TR.step
boards/controller/pcb/symbols/SISA35DN-T1-GE3/SISA35DN-T1-GE3.STEP
boards/bidirectional_load_switch/pcb/symbols/1017503/1017503.step
boards/bidirectional_load_switch/pcb/symbols/UCC23313DWYR/UCC23313DWYR.STEP
boards/controller-old/pcb/symbols/12401826E412A/12401826E412A.step
boards/controller-old/pcb/symbols/12402012E212A/12402012E212A.step
boards/controller-old/pcb/symbols/750315829/750315829.STEP
boards/controller-old/pcb/symbols/PTS526_SK15_SMTR2_LFS/PTS526_SK15_SMTR2_LFS.STEP
boards/controller-old/pcb/symbols/SK34SMA-3G/SK34SMA-3G.step
boards/controller-old/pcb/symbols/USB4105-GF-A/USB4105-GF-A.step
boards/controller-old/pcb/symbols/USB4120_03_C/USB4120-03-C.step
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

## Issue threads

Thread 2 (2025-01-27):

Feature: Design Controller

nicholasnloehrke, 2025-01-27:
### **Motivation**
This project requires a controller capable of generating a PWM signal to drive a bidirectional load switch. The controller shall allow users to adjust the PWM signal's frequency and duty cycle, as well as the load switch resistance.

A previous version utilized an [Arduino UNO R4 WiFi](https://store.arduino.cc/products/uno-r4-wifi), an OLED display, and rotary encoders. This proposal seeks to improve on that design while reducing unnecessary complexity and cost.

---

### **Proposal**
The proposed solution will use the following components:

- **MCU**: [RP2350](https://lectronz.com/products/rp2350-stamp)
- **Display**: [ILI9486](https://a.co/d/eUZY2BM)
- **Input**: Rotary encoders

These components balance cost, ease of use, and performance. If WiFi is needed, an [ESP32 module](https://www.adafruit.com/product/5670?gQT=2) could be used in place of the RP2350.

The RP2350 is particularly appealing due to its PIO capabilities to drive the ILI9486's 16-bit parallel interface. Alternatively, an STM32 with an FMC peripheral could be considered.

---

### **Mockup**
Here’s a simple conceptual diagram of the proposed layout:

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

---

### **Advantages**
- **Hardware Simplification**: MCU and display modules reduce layout complexity.
- **Software Readiness**: I've ported an industry standard graphics library ([LVGL](https://lvgl.io/)) to the RP2350 and ILI9486.

---

### **Next Steps**
1. **Component Finalization**: Confirm the MCU, display, and rotary encoder specifications.
2. **Schematic Design**: Create the circuit schematic in KiCad.
3. **PCB Layout**: Begin designing the PCB based on finalized hardware choices.

nicholasnloehrke, 2025-01-28:
Updated motivation section to include abitily to change load switch resistance

nicholasnloehrke, 2025-02-06:
Combining the PSU into the controller might be a good idea. This would reduce the BOM and not require long wires to connect the STUSB4500 to the MCU.

nicholasnloehrke, 2025-02-06:
> Planning to use STM32xxx since we can't source the RP2350 chip and the castellated modules are pricy when including shipping.

Need to check if STM32U5xx has enough ram for 1 frame buffer (ideally 2 buffers).

nicholasnloehrke, 2025-02-06:
> Planning to use STM32xxx since we can't source the RP2350 chip and the castellated modules are pricy when including shipping.

Need to determine if SMPS sku (STM32U575xxxxQ) is desirable.

nicholasnloehrke, 2025-02-11:
STM32U575x might not have enough IO, might consider [STM32H7B0VBT6](https://www.digikey.com/en/products/detail/stmicroelectronics/STM32H7B0VBT6/11591224) even though this will probably required external flash.

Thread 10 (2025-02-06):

Update block diagrams to reflect BOM changes

nicholasnloehrke, 2025-02-06:
Current block diagrams specify the RP2350 and ILI9488 instead of STM32xxx and the Waveshare display.

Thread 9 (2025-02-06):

Fix documentation CI pushing to main

nicholasnloehrke, 2025-02-06:
The main branch is protected and can only be merged through a PR. Currently, the documentation CI tries to push directly to main and fails.

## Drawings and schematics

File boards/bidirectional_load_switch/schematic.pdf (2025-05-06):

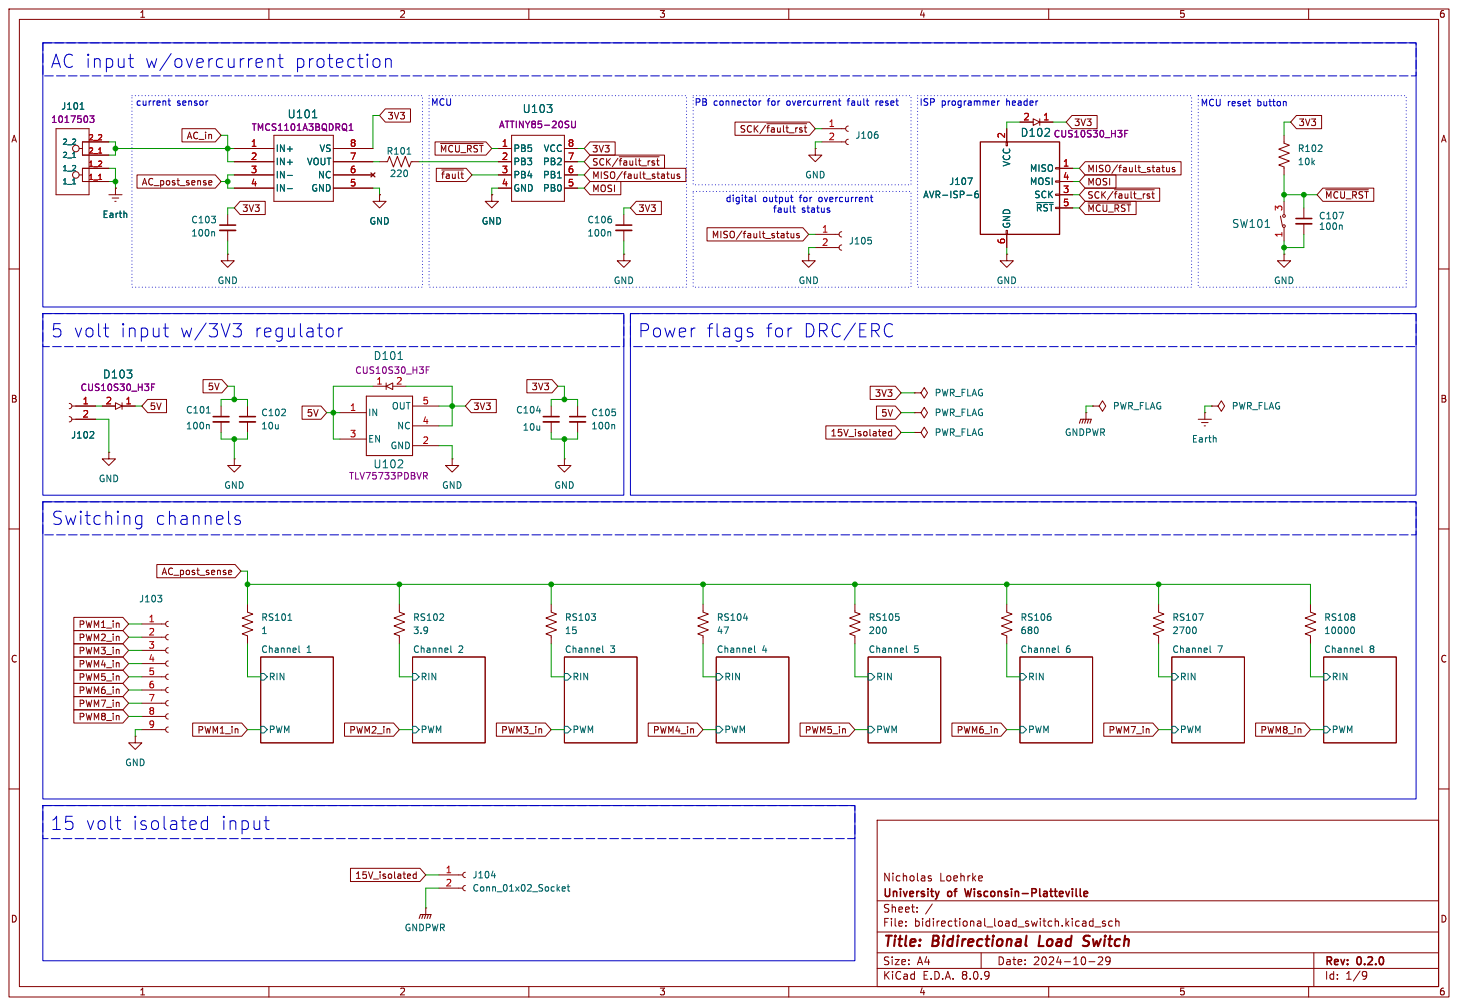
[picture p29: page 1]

MCU reset button Switching channels

2 SCK 3 MOSI 4 ~{RST}5 GND

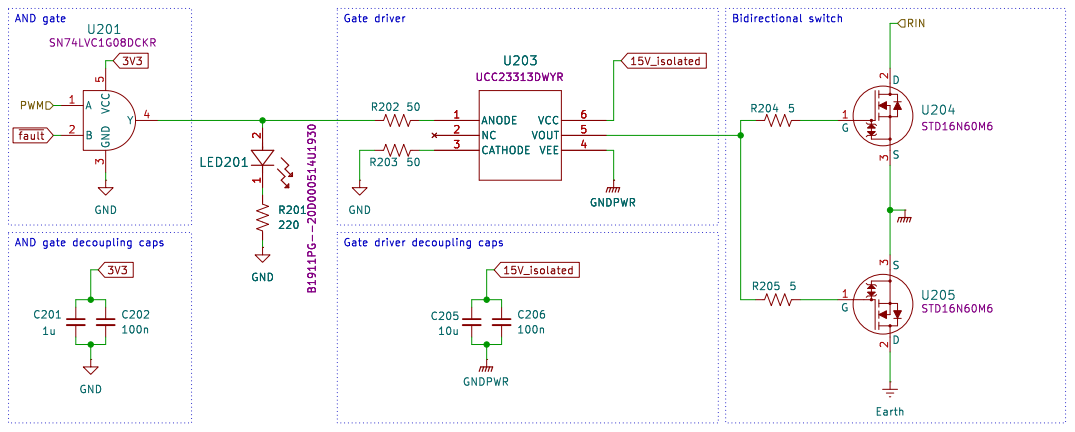
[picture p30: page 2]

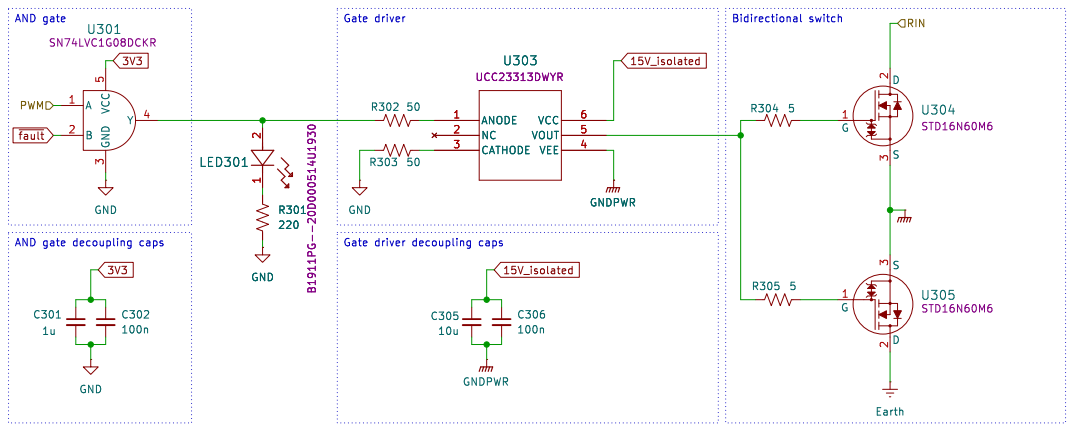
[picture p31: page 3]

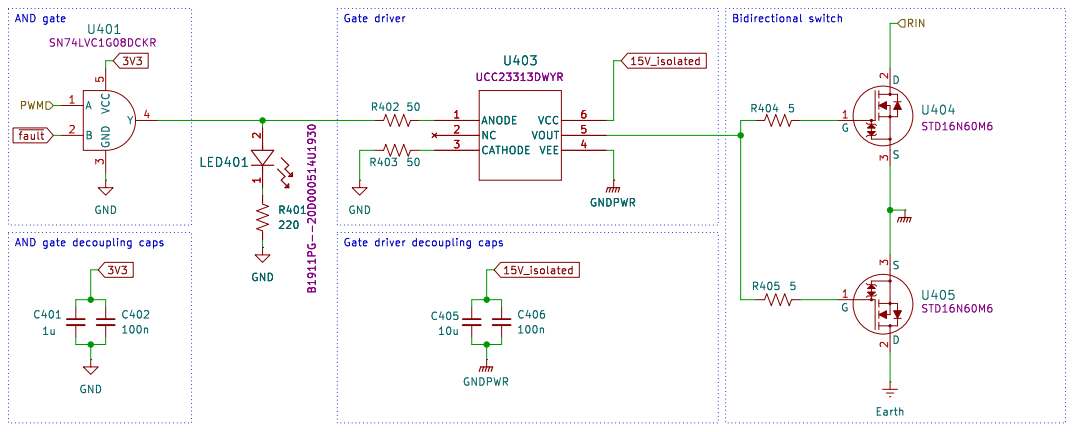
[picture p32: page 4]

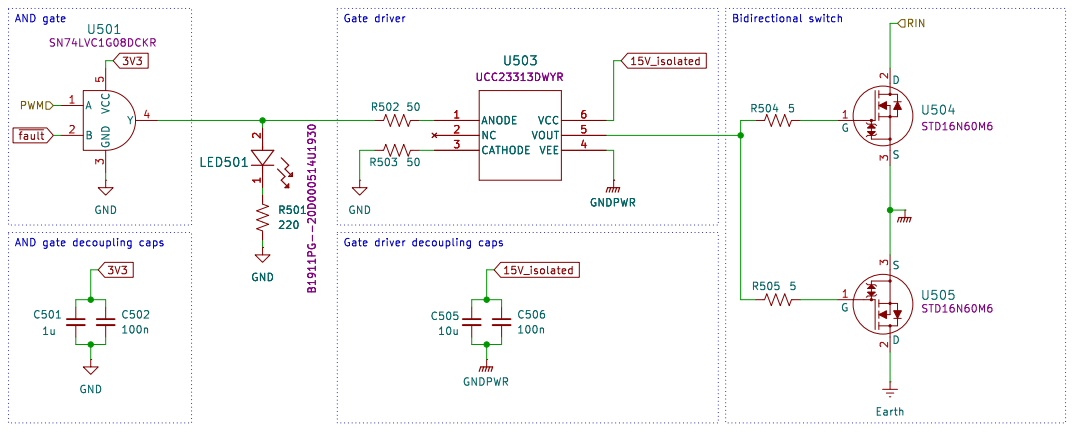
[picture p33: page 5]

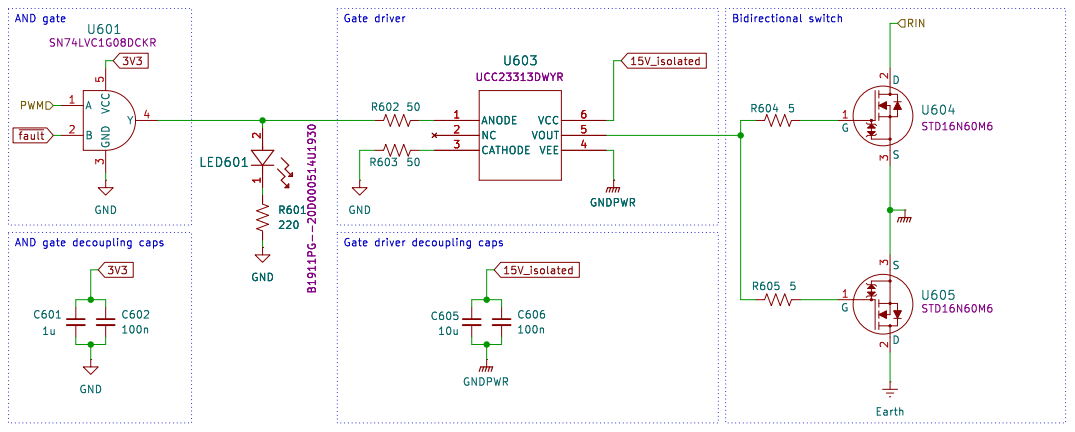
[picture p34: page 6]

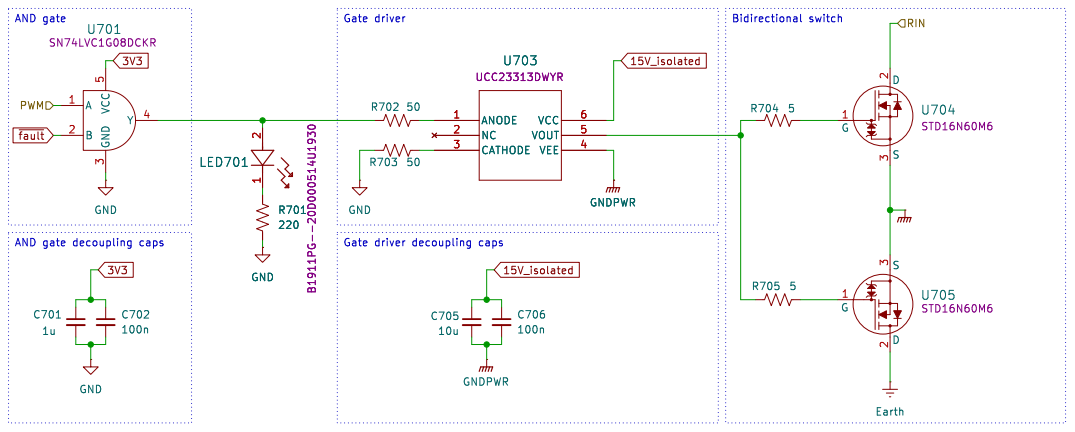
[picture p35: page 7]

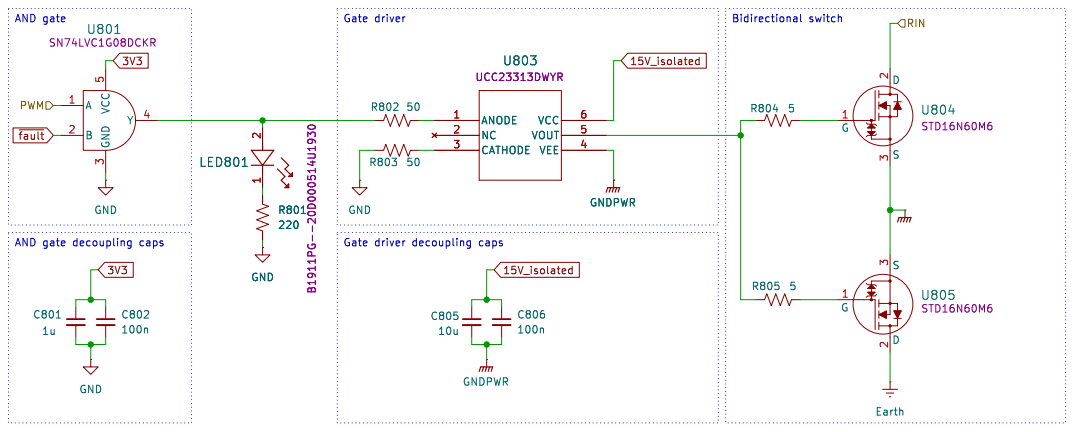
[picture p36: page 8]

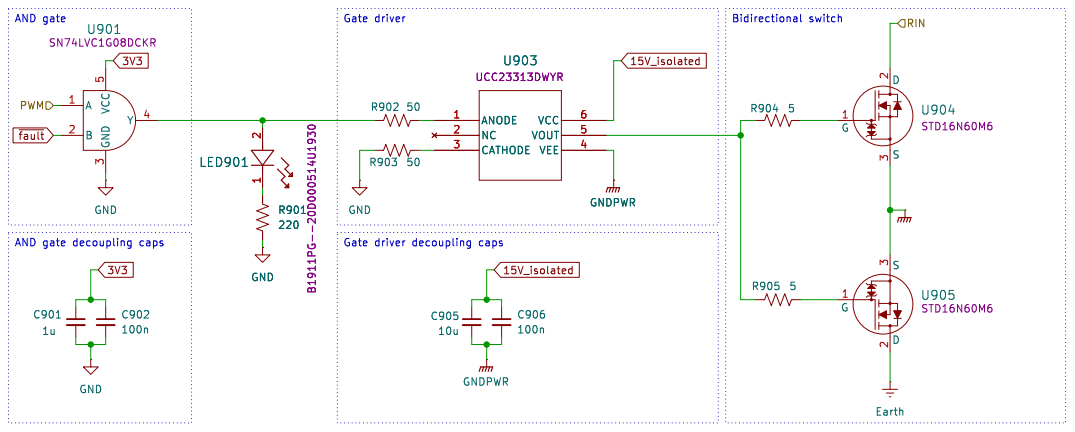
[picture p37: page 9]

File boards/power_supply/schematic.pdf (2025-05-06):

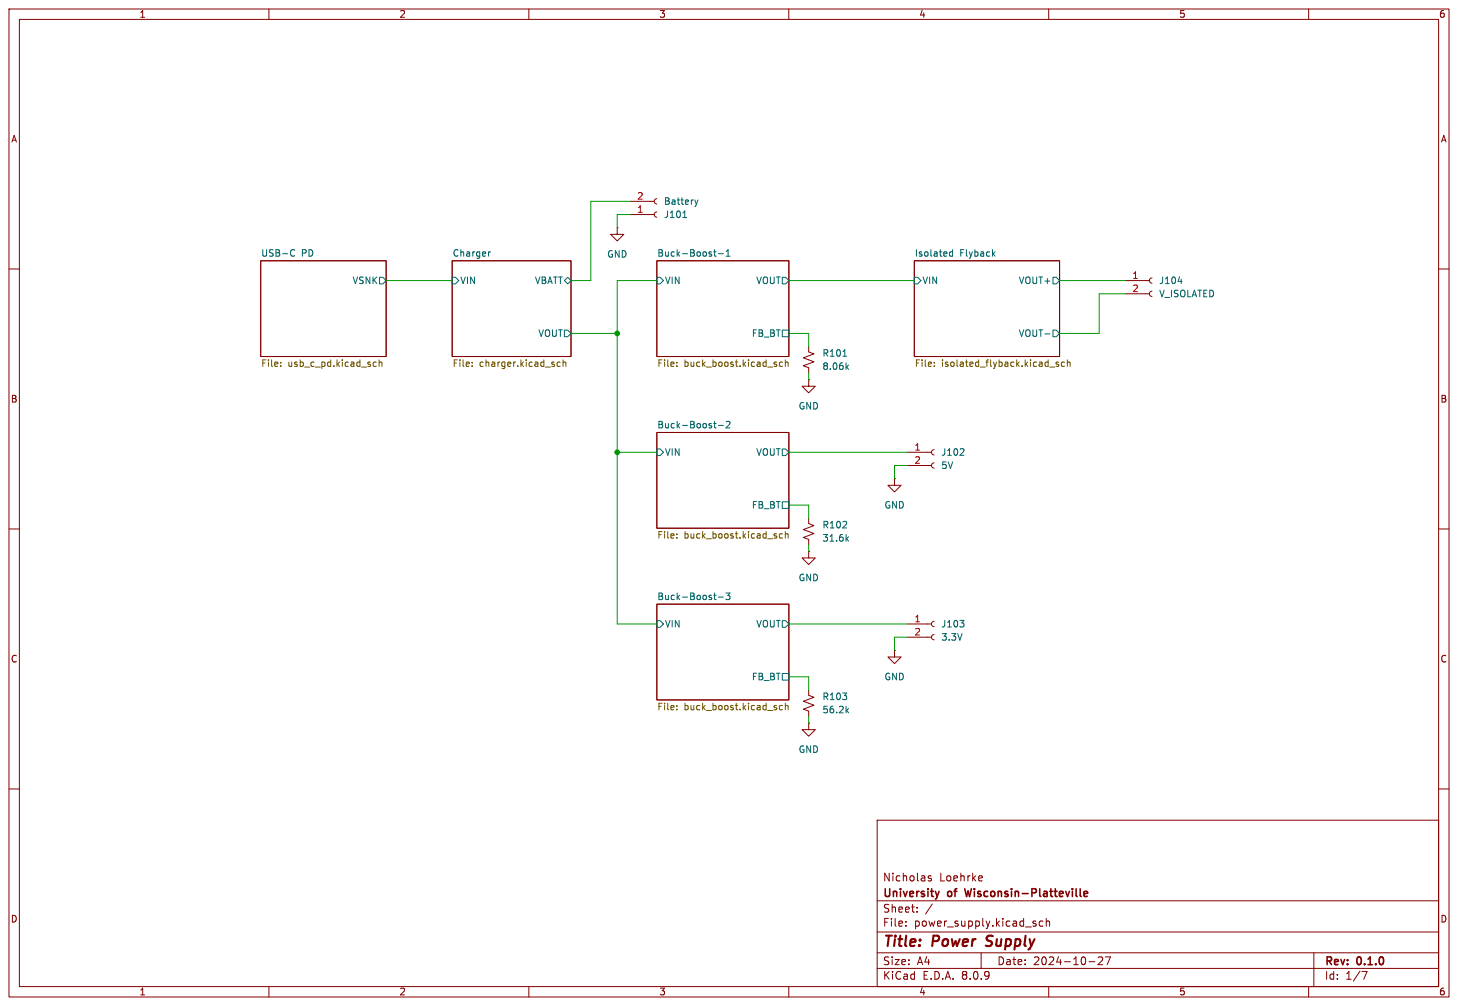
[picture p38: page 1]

Buck-Boost-2 File: buck_boost.kicad_sch VSNK USB-C PD

Id: 1/7 Title: Power Supply

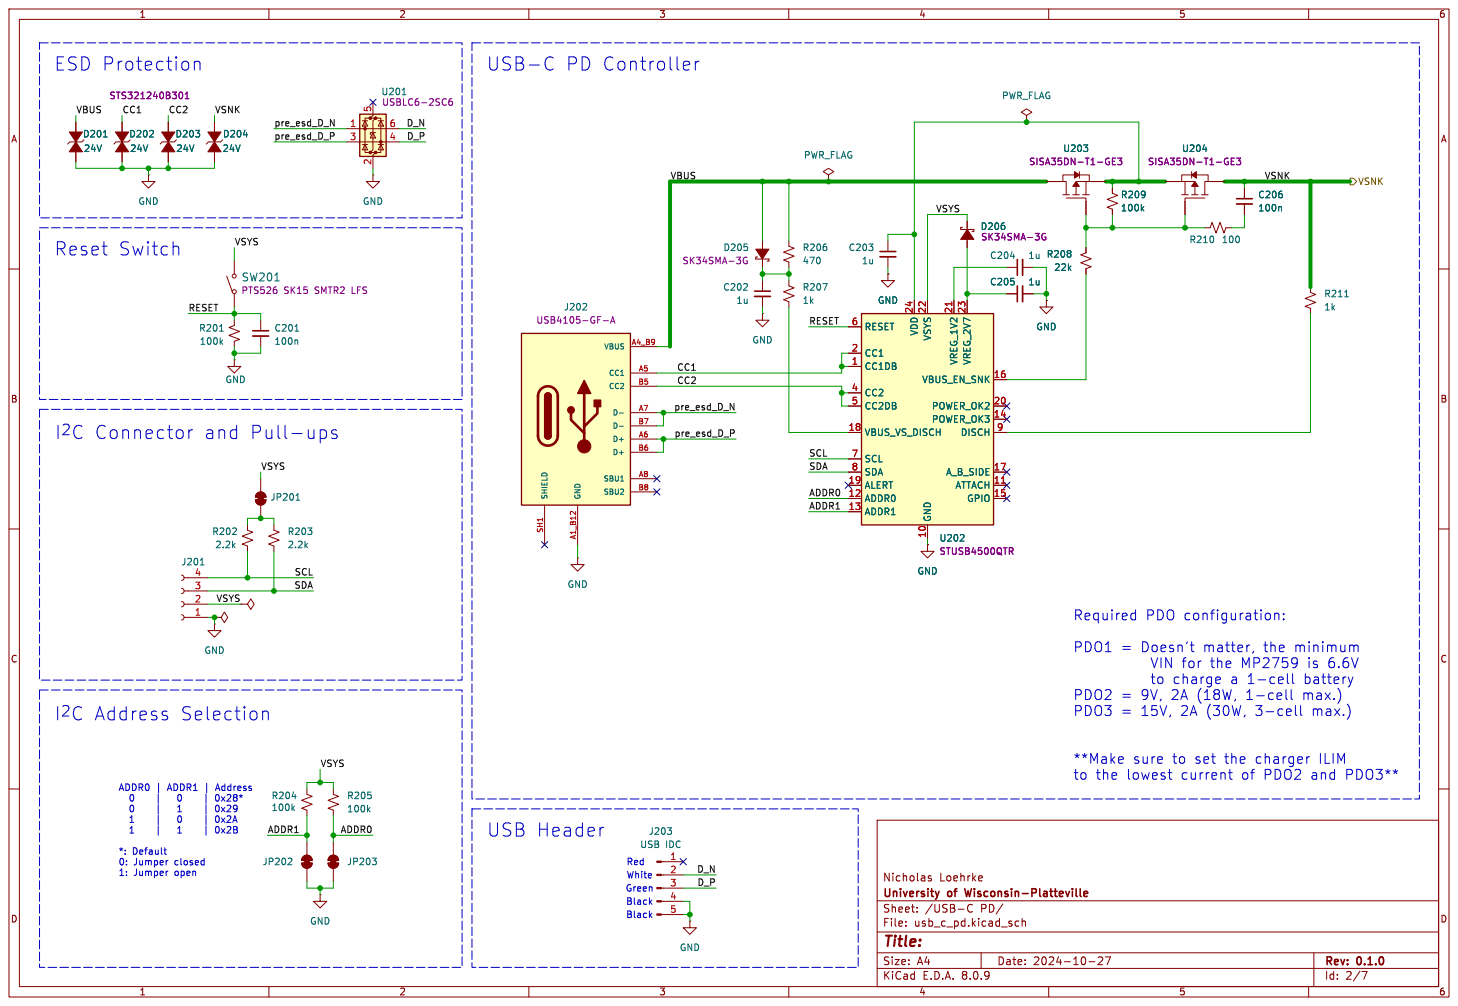
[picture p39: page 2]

SDA D_P D_N Green USB-C PD Controller

I^{2}CConnector and Pull-ups

PDO1 = Doesn't matter, the minimum

**Make sure to set the charger ILIM
to the lowest current of PDO2 and PDO3**

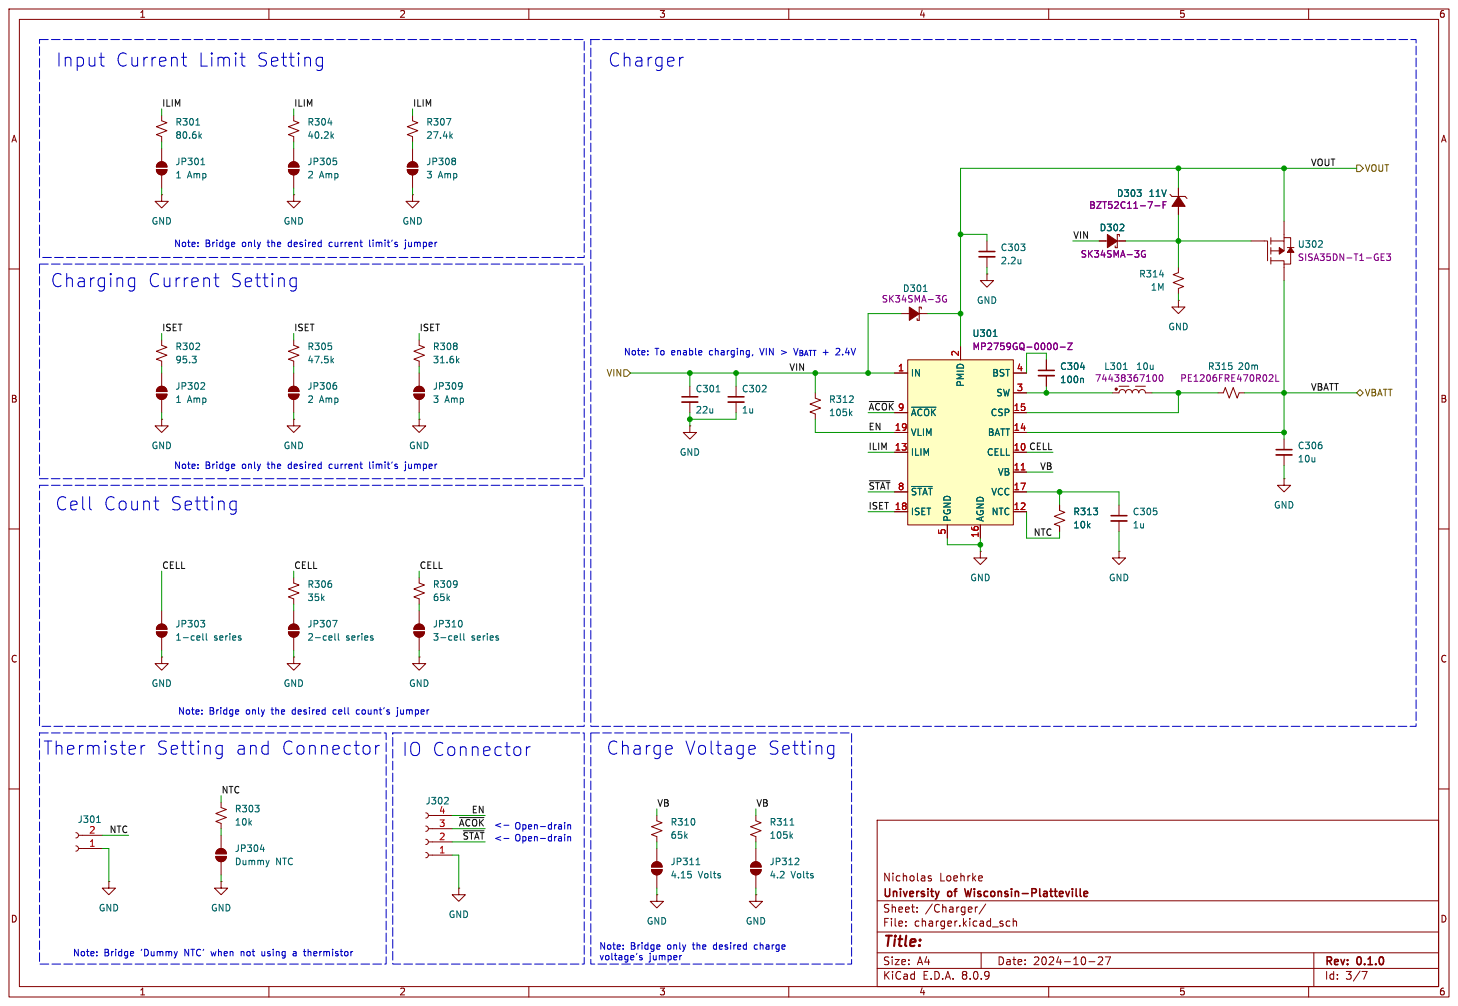
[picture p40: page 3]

Input Current Limit Setting

Id: 3/7 Title: File: charger.kicad_sch Sheet: /Charger/

Note: Bridge only the desired charge


Note: To set output voltage, V_{OUT},
connect 'FB_BT' through R_{FB_BT}
to ground to set output voltage.

Id: 4/7 Title: File: buck_boost.kicad_sch Sheet: /Buck-Boost-1/

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

Id: 5/7 Title: File: buck_boost.kicad_sch Sheet: /Buck-Boost-2/

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

Id: 6/7 Title: File: buck_boost.kicad_sch Sheet: /Buck-Boost-3/


Id: 7/7 Title: Power Supply

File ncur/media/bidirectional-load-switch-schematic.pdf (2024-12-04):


MCU reset button Switching channels

2 SCK 3 MOSI 4 ~{RST}5 GND









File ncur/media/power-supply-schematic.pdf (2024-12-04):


Buck-Boost-2 File: buck_boost.kicad_sch VSNK USB-C PD

Id: 1/7 Title: Power Supply


SDA D_P D_N Green USB-C PD Controller

I^{2}CConnector and Pull-ups

PDO1 = Doesn't matter, the minimum

**Make sure to set the charger ILIM
to the lowest current of PDO2 and PDO3**


Input Current Limit Setting

Id: 3/7 Title: File: charger.kicad_sch Sheet: /Charger/

Note: Bridge only the desired charge


Note: To set output voltage, V_{OUT},
connect 'FB_BT' through R_{FB_BT}
to ground to set output voltage.

Id: 4/7 Title: File: buck_boost.kicad_sch Sheet: /Buck-Boost-1/

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

Id: 5/7 Title: File: buck_boost.kicad_sch Sheet: /Buck-Boost-2/

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

Id: 6/7 Title: File: buck_boost.kicad_sch Sheet: /Buck-Boost-3/


Id: 7/7 Title: Power Supply

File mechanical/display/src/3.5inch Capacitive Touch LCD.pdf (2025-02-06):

92.44(LENS OD) 48.96±0.15⁽LENS VA⁾; 73.44±0.15(LENS VA) 60.98⁽LENS OD⁾

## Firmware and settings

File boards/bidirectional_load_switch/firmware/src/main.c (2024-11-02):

#define F_CPU 8000000UL

#include <avr/io.h>
#include <util/delay.h>

#define PIN_NFAULT         PB4
#define PIN_NFAULT_RESET   PB2
#define PIN_FAULT_STATUS   PB1
#define PIN_CURRENT_SENSOR PB3

int main(void)
{
    DDRB |= (1 << PIN_FAULT_STATUS);
    DDRB |= (1 << PIN_NFAULT);
    PORTB |= (1 << PIN_NFAULT);
    
    while (1)
    {
        PORTB |= (1 << PIN_FAULT_STATUS);
        _delay_ms(50);

        PORTB &= ~(1
         << PIN_FAULT_STATUS);
        _delay_ms(50);
    }
}

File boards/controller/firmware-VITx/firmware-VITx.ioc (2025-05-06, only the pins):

Mcu.UserName=STM32U575VITx
PA0.Signal=S_TIM5_CH1
PA1.Signal=S_TIM5_CH2
PA10.Signal=USART1_RX
PA11.Signal=USB_OTG_FS_DM
PA12.Signal=USB_OTG_FS_DP
PA2.Signal=S_TIM2_CH3
PA3.Signal=S_TIM2_CH4
PA5.Signal=S_TIM2_CH1
PA9.Signal=USART1_TX
PB15.Signal=UCPD1_CC2
PB6.Signal=I2C1_SCL
PB7.Signal=I2C1_SDA
PD12.Signal=S_TIM4_CH1
PD13.Signal=S_TIM4_CH2
PD14.Signal=S_TIM4_CH3
PD15.Signal=S_TIM4_CH4
PD5.Signal=USART2_TX
PD6.Signal=USART2_RX
PE13.Signal=SPI1_SCK
PE14.Signal=SPI1_MISO
PE15.Signal=SPI1_MOSI
PE3.Signal=S_TIM3_CH1
PE4.Signal=S_TIM3_CH2
PE5.Signal=S_TIM3_CH3
PE6.Signal=S_TIM3_CH4

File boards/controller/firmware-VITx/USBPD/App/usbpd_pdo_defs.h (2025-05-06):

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

#ifndef __USBPD_PDO_DEF_H_
#define __USBPD_PDO_DEF_H_

#ifdef __cplusplus
 extern "C" {
#endif

/* Includes ------------------------------------------------------------------*/
#include "usbpd_def.h"

/* Define   ------------------------------------------------------------------*/
#define PORT0_NB_SOURCEPDO         0U   /* Number of Source PDOs (applicable for port 0)   */
#define PORT0_NB_SINKPDO           1U   /* Number of Sink PDOs (applicable for port 0)     */
#define PORT1_NB_SOURCEPDO         0U   /* Number of Source PDOs (applicable for port 1)   */
#define PORT1_NB_SINKPDO           0U   /* Number of Sink PDOs (applicable for port 1)     */

/* Exported typedef ----------------------------------------------------------*/

/* USER CODE BEGIN typedef */
/**
  * @brief  USBPD Port PDO Structure definition
  *
  */
/* USER CODE END typedef */

/* Exported define -----------------------------------------------------------*/

/* USER CODE BEGIN Exported_Define */

#define USBPD_CORE_PDO_SRC_FIXED_MAX_CURRENT 3
#define USBPD_CORE_PDO_SNK_FIXED_MAX_CURRENT 1500

/* USER CODE END Exported_Define */

/* Exported constants --------------------------------------------------------*/

/* Exported macro ------------------------------------------------------------*/

/* Exported variables --------------------------------------------------------*/

#ifndef __USBPD_PWR_IF_C
extern uint32_t PORT0_PDO_ListSRC[USBPD_MAX_NB_PDO];
extern uint32_t PORT0_PDO_ListSNK[USBPD_MAX_NB_PDO];
#else
/* Definition of Source PDO for Port 0 */
uint32_t PORT0_PDO_ListSRC[USBPD_MAX_NB_PDO] =
{
  /* PDO 1 */ (0x00000000U),

  /* PDO 2 */ (0x00000000U),

  /* PDO 3 */ (0x00000000U),

  /* PDO 4 */ (0x00000000U),

  /* PDO 5 */ (0x00000000U),

  /* PDO 6 */ (0x00000000U),

  /* PDO 7 */ (0x00000000U),

};

/* Definition of Sink PDO for Port 0 */
uint32_t PORT0_PDO_ListSNK[USBPD_MAX_NB_PDO] =
{

  /* PDO 1 */
  (
    USBPD_PDO_TYPE_FIXED                 | /* Fixed supply PDO            */

    USBPD_PDO_SNK_FIXED_SET_VOLTAGE(5000U)         | /* Voltage in mV               */
    USBPD_PDO_SNK_FIXED_SET_OP_CURRENT(300U)     | /* Operating current in  mA            */

    /* Common definitions applicable to all PDOs, defined only in PDO 1 */
    USBPD_PDO_SNK_FIXED_FRS_NOT_SUPPORTED          | /* Fast Role Swap				 */
    USBPD_PDO_SNK_FIXED_DRD_SUPPORTED          | /* Dual-Role Data              */
    USBPD_PDO_SNK_FIXED_USBCOMM_NOT_SUPPORTED      | /* USB Communications          */
    USBPD_PDO_SNK_FIXED_EXT_POWER_NOT_AVAILABLE    | /* External Power              */
    USBPD_PDO_SNK_FIXED_HIGHERCAPAB_NOT_SUPPORTED   | /* Higher Capability           */
    USBPD_PDO_SNK_FIXED_DRP_NOT_SUPPORTED            /* Dual-Role Power             */
  ),

  /* PDO 2 */ (0x00000000U),

  /* PDO 3 */ (0x00000000U),

  /* PDO 4 */ (0x00000000U),

  /* PDO 5 */ (0x00000000U),

  /* PDO 6 */ (0x00000000U),

  /* PDO 7 */ (0x00000000U),
};

#endif

/* Exported functions --------------------------------------------------------*/

#ifdef __cplusplus
}
#endif

#endif /* __USBPD_PDO_DEF_H_ */

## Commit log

2024-09-12 created kicad project
    [87s.kicad_pcb, 87s.kicad_sch]
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2024-09-16 added resistor code and updated kicad schematic
    [87s.kicad_pcb, 87s.kicad_sch, RTBS60M.step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]
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2024-09-18 implementing switch design
    [DCK0005A.stp, bidirectional_load_switch.kicad_pcb, bidirectional_load_switch.kicad_sch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]
2024-09-18 updated switch topology
    [bidirectional_load_switch.kicad_pcb, bidirectional_load_switch.kicad_sch, switching_channel.kicad_sch]
2024-10-04 load switch
    [DFN_V33R_STM.step, bidirectional_load_switch.kicad_pcb, bidirectional_load_switch.kicad_sch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]
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2024-10-11 i hate layouts
    [8S2_ATM.step, DCK0005A.stp, DCU0008A.stp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]
2024-10-13 needs review
    [PTS525SM15SMTR2LFS--3DModel-STEP-56544.STEP, bidirectional_load_switch.kicad_pcb, bidirectional_load_switch.kicad_sch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]
2024-10-14 updated layout and silkscreen
    [bidirectional_load_switch.kicad_pcb]
2024-10-14 generated gerbers
    [bidirectional_load_switch-B_Mask.gbr, bidirectional_load_switch-B_Silkscreen.gbr, bidirectional_load_switch-Back.gbr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]
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2024-10-14 added series diode for ISP 3V3 rail
    [bidirectional_load_switch.kicad_pcb, bidirectional_load_switch.kicad_sch]
2024-10-14 ready for order
    [bidirectional_load_switch-B_Cu.gbl, bidirectional_load_switch-B_Cu.gbr, bidirectional_load_switch-B_Mask.gbs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]
2024-10-14 updated gerbers
    [bidirectional_load_switch-B_Cu.gbl, bidirectional_load_switch-B_Mask.gbs, bidirectional_load_switch-B_Paste.gbp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]
2024-10-15 removed redundant buffer
    [bidirectional_load_switch-B_Cu.gbl, bidirectional_load_switch-B_Mask.gbs, bidirectional_load_switch-B_Paste.gbp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]
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2024-10-15 added ordering information
    [digikey_bom.xlsx]
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2024-10-16 added media generation script
    [bidirectional_load_switch.kicad_pcb]
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2024-10-16 updated schematic
    [switching_channel.kicad_sch]
2024-10-16 added media generation
    [bidirectional_load_switch-B_Cu.gbl, bidirectional_load_switch-B_Mask.gbs, bidirectional_load_switch-B_Paste.gbp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]
2024-10-16 updated media generation
    [bidirectional_load_switch-B_Cu.gbl, bidirectional_load_switch-B_Mask.gbs, bidirectional_load_switch-B_Paste.gbp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]
2024-10-16 increased pwm trace spacing
    [bidirectional_load_switch.kicad_pcb]
2024-10-16 updated gerbers and added automatic gerber generation bat file
    [bidirectional_load_switch-CmtUser.gbr, bidirectional_load_switch-CuBottom.gbl, bidirectional_load_switch-CuTop.gtl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]
2024-10-16 updated bom
    [bidirectional_load_switch.kicad_pcb]
2024-10-17 updated connector polarity
    [bidirectional_load_switch.kicad_pcb, bidirectional_load_switch.kicad_sch]
2024-10-17 updated layout silkscreen
    [87s_scope_setup.stp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]
2024-10-21 added timesheet
    [timesheet.xlsx]
2024-10-23 updated timesheet
    [timesheet.xlsx]
2024-10-25 updated psu
    [power_supply.kicad_pcb]
2024-10-27 finalizing psu topologies
    [LM25183.xlsx]
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2024-10-28 working on psu schematic capture
    [12401826E412A.step, 5_volt_dc_to_dc.kicad_sch, DCK0005A.stp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]
2024-10-28 psu buck-boost schematic capture
    [buck_boost.kicad_sch, power_supply.kicad_sch, usb_c_pd.kicad_sch]
2024-10-29 implementing 5v and 3v3 supply ORing
    [bidirectional_load_switch.kicad_pcb, bidirectional_load_switch.kicad_sch, switching_channel.kicad_sch]
2024-10-29 added 5v and 3v3 supply ORing and revised silkscreen text
    [bidirectional_load_switch.kicad_pcb, bidirectional_load_switch.kicad_sch]
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2024-10-30 improved load switch mosfet paste aperture
    [LM25183.xlsx, LM5181NGUR.stp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]
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2024-10-31 added load switch paste DXF and Lightburn project
    [paste.dxf]
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2024-11-02 created interactive html bom for load switch
    [bidirectional_load_switch.kicad_pcb]
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2024-11-11 initial psu charger layout
    [12402012E212A.step, 1N4148W-13-F.STEP, 74438367010.stp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]
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2025-01-27 Add controller mockup KiCad project
    [mockup.kicad_pcb, mockup.kicad_sch]
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2025-02-06 mechanical: Add initial display files
    [3.5inch Capacitive Touch LCD.dwg]
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2025-02-06 controller: Update mockup to use Waveshare display
    [mockup.kicad_pcb, mockup.kicad_sch]
2025-03-07 controller: Update
    - Added controller MX project
    - Added controller KiCad project
    - Added controller MCU requirements
    - Update .gitignore for vim
    - Remove .vscode directory
    - Update controller MCU requirements
    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
    [12401826E412A.step, 12402012E212A.step, 1N4148W-13-F.STEP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]
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2025-03-21 controller: Migrate to KiCad 9
    [battery_adc.kicad_sch, buck_boost.kicad_sch, charger.kicad_sch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]
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2025-04-01 controller: pcb: Update schematic
    [1N4148W-13-F.STEP, 300SP1J1BLKM2QE.step, 74438367010.stp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]
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2025-04-28 controller: pcb: Update schematic
    - Replace 22u caps with 10u since 22u are very expensive
    - Add TCC and MPN fields
    [bls_interface.kicad_sch, charger.kicad_sch, encoder.kicad_sch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]
2025-04-30 controller: pcb: Update schematic
    - Add power button pmos gate voltage clamp
    - Add TVS diodes on encoders
    [PJSD03TS-AU_R1_000A1.step, buck_converter_5v.kicad_sch, charger.kicad_sch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]
2025-04-30 controller: pcb: Update schematic
    - Add TVS diodes on select MCU pins
    [BZT52C18K_RKG.step, encoder.kicad_sch, isolated_flyback.kicad_sch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]
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

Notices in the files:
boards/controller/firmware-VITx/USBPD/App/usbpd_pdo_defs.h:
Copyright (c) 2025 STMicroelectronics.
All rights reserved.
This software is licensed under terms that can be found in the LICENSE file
